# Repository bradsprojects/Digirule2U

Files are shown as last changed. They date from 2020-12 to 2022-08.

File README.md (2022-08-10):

# Digirule 2U by Brad Slattery and Brent Hauser

The Digirule 2U is basically an 8-bit programmable computer from the 1970's built into a 20cm ruler. You can program binary code directly into the Digirule 2U using the push buttons and LED's or you can write programs in assembly language on your computer then download them to the Digirule 2U via USB.

All files to make your own Digirule 2U are included in this repository, however you can also buy a pre-made version from my Tindie store - (https://www.tindie.com/products/bradsprojects/digirule2-the-8-bit-programmable-binary-ruler/)

There are online versions of the user manuals available here:

1. Digirule 2U User Manual (https://hackmd.io/@zrqJxVrZQz-EScD0kFIEYg/rJ6S9s4SP)
2. ADR2 Digirule 2U Cross-Assembler User Manual (https://hackmd.io/@zrqJxVrZQz-EScD0kFIEYg/rJ3bYYtqw)
3. DLDR2 Digirule 2U Download Utility User Manual (https://hackmd.io/@zrqJxVrZQz-EScD0kFIEYg/rkCUtKF9v)
4. UDR2 Digirule 2U Firmware Updater User Manual (https://hackmd.io/@zrqJxVrZQz-EScD0kFIEYg/B1gSKYK5w)
5. Digirule 2U FAQs (https://hackmd.io/@zrqJxVrZQz-EScD0kFIEYg/HkEHDYwAD)

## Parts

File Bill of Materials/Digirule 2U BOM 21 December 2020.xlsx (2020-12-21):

Digirule 2U BOM
Item | Reference | Qty | Description | Manufacturer Part Number | Manufacturer | Digikey Part Number | LCSC Part Number | Link
1 | B1 | 1 | CR2032 Battery Holder SMD | BS-8-1 | Q&J |  | C70378 | LINK (https://lcsc.com/product-detail/Battery-Holders-Clips-Contacts_CR2032battery-Gold-plated-patch-horizontal-base_C70378.html)
2 | C1, C2, C5, C9 | 4 | 0402 100nF Capacitor | CL05B104KO5NNNC | Samsung Electro-Mechanics |  | C1525 | LINK (https://lcsc.com/product-detail/Multilayer-Ceramic-Capacitors-MLCC-SMD-SMT_SAMSUNG_CL05B104KO5NNNC_100nF-104-10-16V_C1525.html)
3 | C3, C4 | 2 | 0402 4.7uF Capacitor | JMK105BBJ475MV-F | Taiyo Yuden |  | C87147 | LINK (https://lcsc.com/product-detail/Multilayer-Ceramic-Capacitors-MLCC-SMD-SMT_TAIYO-YUDEN_JMK105BBJ475MV-F_4-7uF-475-20-6-3V_C87147.html)
4 | C6 | 1 | 0402 10nf Capacitor | TCC0402X7R103K500AT | CCTC |  | C688874 | LINK (https://lcsc.com/product-detail/Multilayer-Ceramic-Capacitors-MLCC-SMD-SMT_CCTC-TCC0402X7R103K500AT_C688874.html)
5 | C7, C8 | 2 | 0402 47pF Capacitor | 0402CG470J500NT | FH(Guangdong Fenghua Advanced Tech) |  | C1567 | LINK (https://lcsc.com/product-detail/Multilayer-Ceramic-Capacitors-MLCC-SMD-SMT_FH-Guangdong-Fenghua-Advanced-Tech-0402CG470J500NT_C1567.html)
6 | D1, D2, D3, D4, D5, D6, D7, D8, D9, D10, D11, D12, D13, D14, D15, D16, D17, D18 | 18 | 0805 Red LED | FC-2012HRK-620D | Foshan NationStar Optoelectronics |  | C84256 | LINK (https://lcsc.com/product-detail/Light-Emitting-Diodes-LED_Red-LED-SMDLED-80-180mcd_C84256.html)
7 | D19, D20 | 2 | 30V, 800mA 220mV @ 10mA SOD-323 Schottky Diode | CUS08F30,H3F | Toshiba |  | C150183 | LINK (https://lcsc.com/product-detail/Schottky-Barrier-Diodes-SBD_TOSHIBA_CUS08F30-H3F_CUS08F30-H3F_C150183.html)
8 | FB1 | 1 | 0402 Ferrite Bead 600ohm @ 100MHz | BLM15AX601SN1D | Murata Electronics |  | C76886 | LINK (https://lcsc.com/product-detail/Ferrite-Beads_Murata-Electronics_BLM15AX601SN1D_Murata-Electronics-BLM15AX601SN1D_C76886.html)
9 | J1 | 1 | USB - Type C Female 16 SMD USB Connectors RoHS | C167321 | Jing Extension of the Electronic Co. |  | C167321 | LINK (https://lcsc.com/product-detail/USB-Connectors_Jing-Extension-of-the-Electronic-Co-C167321_C167321.html)
10 | R1, R2, R3, R4, R5, R6, R7, R8, R9, R10, R11, R12, R13, R14, R15, R16, R17, R18, R28 | 19 | 0402 1k 5% tolerance thick film resistor | RC0402JR-071KL | YAGEO |  | C105637 | LINK (https://lcsc.com/product-detail/Chip-Resistor-Surface-Mount_1KR-102-5_C105637.html)
11 | R19, R20, R21, R22, R23, R24, R25, R29, R30 | 9 | 0402 10k 5% tolerance thick film resistor | RC0402FR-0710KL | YAGEO |  | C60490 | LINK (https://lcsc.com/product-detail/Chip-Resistor-Surface-Mount_10KR-1002-1_C60490.html)
12 | R26, R27 | 2 | 27Ω ±1% 1/16W ±1% ±200ppm/℃ 0402 Chip Resistor - Surface Mount RoHS | 0402WGF270JTCE | Viking Tech |  | C25100 | LINK (https://lcsc.com/product-detail/Chip-Resistor-Surface-Mount_UNI-ROYAL-Uniroyal-Elec-0402WGF270JTCE_C25100.html)
13 | R31, R32 | 2 | 0402 5.1k 5% tolerance thick film resistor | AR02DTD5101 | UNI-ROYAL(Uniroyal Elec) |  | C319557 | LINK (https://lcsc.com/product-detail/Others_Viking-Tech-AR02DTD5101_C319557.html)
14 | SW1, SW2, SW3, SW4, SW5, SW6, SW7, SW8, SW9, SW10, SW11, SW12, SW13, SW14, SW15 | 15 | SMD Button 6*6*2.5mm | K2-1157SP-C4SB-01 | Korean Hroparts Elec |  | C128947 | LINK (https://lcsc.com/product-detail/Tactile-Switches_Switch-6-4mm-6-0mm-3-1_C128947.html)
15 | SW16 | 1 | Power Slide Switch SMD | K3-1296S-E2 | Korean Hroparts Elec |  | C136659 | LINK (https://lcsc.com/product-detail/Toggle-Switches_K3-1296S-E2_C136659.html)
16 | U1 | 1 | PIC18F46K20-I/PT | PIC18F46K20-I/PT | Microchip Tech |  | C70902 | LINK (https://lcsc.com/product-detail/MICROCHIP_MICROCHIP_PIC18F46K20-I-PT_PIC18F46K20-I-PT_C70902.html)
17 | U2 | 1 | USB to UART 12-DFN(3x3) | FT-234XD-R | FTDI | 768-1178-1-ND |  | LINK (https://www.digikey.com/product-detail/en/ftdi-future-technology-devices-international-ltd/FT234XD-R/768-1178-1-ND/3904926)
18 | U3 | 1 | LVC Single AND Gate | SN74LVC1G08DCKR | Texas Instruments |  | C7832 | LINK (https://lcsc.com/product-detail/Gates-and-Inverters_Texas-Instruments_SN74LVC1G08DCKR_Texas-Instruments-Texas-Instruments-SN74LVC1G08DCKR_C7832.html)

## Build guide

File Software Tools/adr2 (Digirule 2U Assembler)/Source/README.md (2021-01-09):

Compile adr2 (Digirule 2U Cross-Assembler)
-------------------------------------------

You can compile the Digirule 2U Cross-Assembler from the terminal under Linux or Mac OS, or from the command prompt under Windows.

Note: You will need to make sure that git and gcc are installed on your system before running the following commands.

For Linux, use the following:
```
git clone https://github.com/bradsprojects/Digirule2U
cd Digirule2U/Software\ Tools/adr2\ \(Digirule\ 2U\ Assembler\)/Source
gcc -Wall -Os -s *.c -o adr2
```

For Mac OS, use the following:
```
git clone https://github.com/bradsprojects/Digirule2U
cd Digirule2U/Software\ Tools/adr2\ \(Digirule\ 2U\ Assembler\)/Source
gcc -Wall -Os *.c -o adr2
```

For Windows, use following:
```
git clone https://github.com/bradsprojects/Digirule2U
cd Digirule2U\Software Tools\adr2 (Digirule 2U Assembler)\Source
gcc -Wall -Os -s *.c -o adr2.exe
```

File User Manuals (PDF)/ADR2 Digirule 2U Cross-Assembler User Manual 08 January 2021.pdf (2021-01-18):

# ADR2 Digirule 2U Cross-Assembler User Manual

8 January 2021

# Introduction

ADR2 is a traditional style command line cross-assembler for the Digirule 2U. Its purpose is to translate assembly language program source into machine code for downloading to the Digirule 2U. Versions are available for Linux, Mac OS and Windows.

The assembler has the following features:

Supports the entire Digirule 2U instruction set
Supports directives for control of the assembly and listing process
Supports definition of symbolic names to represent memory addresses and constants Supports symbolic expressions with a comprehensive set of operators
Supports pre-defined symbols for commonly-used Digirule 2U resources
Supports numbers represented in binary, decimal, hexadecimal and character notation Produces a formatted listing file which includes location counter, machine code, source line, symbol table and RAM usage information
Two-pass assembly
Directly produces machine code in Intel Hex format for download to the Digirule 2U

# Invoking the Assembler

The assembler is invoked using the following general syntax:

The assembler reads the source input from standard input by default, so it may be redirected from a file, device or another program as desired. The assembler writes the hex output to standard output by default, so it may be redirected to a file, device or another program as desired.

The assembler supports the following command-line options:

adr2 [options] <sourcefile >hexfile

Option | Function
--quiet | suppress banner and completion info
--nolist | suppress listing file creation
--list [path] | specify alternate listing file pathname (default is adr2.lst )
--help | display help information

Here are a few examples of how to invoke the assembler:

listing to adr2.lst , hex to sample.hex

no listing, hex to sample.hex

listing to sample.lst , hex to sample.hex

listing to sample.lst , hex downloaded to Digirule 2U^*^ (Linux)

listing to sample.lst , hex downloaded to Digirule 2U^*^ (via dldr2 download utility, Mac)

listing to sample.lst , hex downloaded to Digirule 2U^*^ (Windows)

Tip: For Windows, if the port device name is COM10 or greater, it must be specified as

\\.\COMnn
^*^This example requires the Digirule 2U to be in Comm Load Mode prior to execution. Please refer to the Digirule 2U User Manual for details on setting the mode.

The assembler returns a value to the operating system indicating if errors or warnings were encountered during assembly.

adr2 < sample.asm > sample.hex

adr2 --nolist < sample.asm > sample.hex

adr2 --list sample.lst < sample.asm > sample.hex

stty -F /dev/ttyUSB0 9600 cs8 -parenb -cstopb adr2 --list sample.lst < sample.asm > /dev/ttyUSB0

adr2 --list sample.lst < sample.asm | dldr2 /dev/tty.usbserial-FTxxxxxx

mode COM3 baud=9600 data=8 parity=n stop=1 adr2 --list sample.lst < sample.asm > COM3

Return Value | Meaning
0 | Success
1 | Warning(s)
2 | Error(s)
3 | Fatal error
Category | Characters
Whitespace | space, horizontal tab
Letters | A..Z, a..z
Digits | 0..9
Punctuation | ! " # $ % & ' ( ) * + , - . / : ; < = > ? @ [ \ ] ^ _ ` { | } ~
Line Feed | 0x0A

# Assembler Input

The assembler recognizes the following characters for source input. All other characters are ignored.

# Source File Format

A program is written as one or more source files. A source file consists of source lines, each with a specific format. The main source file typically starts with an ORG directive to set the initial location counter, and an END directive to mark the end of assembly (and optionally specify the program entry point).

Tip: If the ORG directive is omitted, the location counter defaults to 0 at the beginning of assembly.

Tip: If the END directive is omitted, assembly stops at the end of the file, and the program entry point defaults to 0.

## Source Line Format

Each source line has a specific format consisting of up to four fields. Fields are separated by whitespace (one or more horizontal tab or space characters), so fields may not contain whitespace. The exceptions are inside quoted character constant operands and comments. The fields, in order from left to right, are:

Label Field

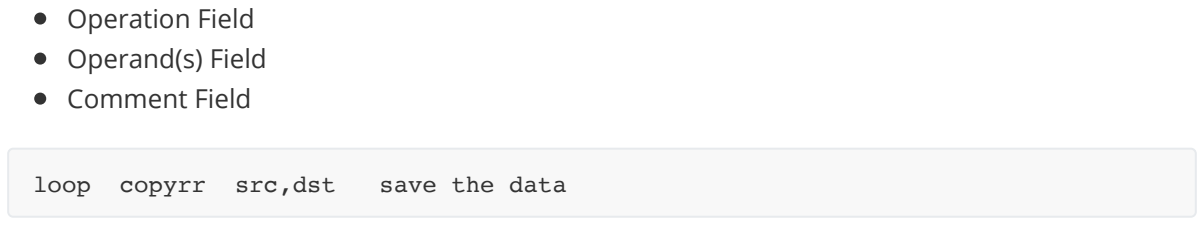
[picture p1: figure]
Operation Field Operand(s) Field Comment Field; loop; copyrr; src,dst; save the data

The maximum length of a line is 255 characters. Any characters beyond this limit are ignored.

## Label Field

The label field optionally contains a user-defined label. If a label is present, its first character must be an underscore or a letter. Subsequent characters may be underscores, letters or digits. The maximum length of a label is 255 characters. Labels are case-sensitive, i.e. LOOP and loop are distinct. A label will assume the current value of the location counter unless the operation field is the EQU directive, in which case the label will assume the value of the expression following the directive.

## Operation Field

The operation field optionally contains an instruction mnemonic or an assembler directive. If no instruction is present, no machine code will be emitted for that line. Instruction mnemonics and directives are not case sensitive.

## Operand Field

The operand field contains any operand(s) required by the operation field instruction or directive. If multiple operands are required, they must be separated by commas. It is an error to have too few or too many operands for a given operation.

## Comment Field

The comment field optionally contains human readable text typically used to document the program. The assembler ignores the contents of this field, except that it is written to the listing file.

Tip: If a comment is desired on a line lacking an operation or operand, the comment must begin with a semicolon ; .

Tip: A line that begins with an asterisk * or a semicolon ; is treated as a comment and ignored.

# Directives

The assembler supports the following directives:

Directive | Function
BYTE exp [,...] | Defines one or more bytes starting at the current location counter and initializes them to exp [,...]
END [exp] | Optionally marks the end of the assembly source file. Any lines that follow will be ignored. The optional exp specifies the program entry point, which will be automatically loaded into the Digirule 2U Program Counter upon download.
label EQU exp | Assigns the new symbol label the value exp. This is the only way to assign a value other than the location counter to a label. exp must not reference a forward or undefined symbol.
INCLUDE file | Include the contents of another source file. Included files may themselves include other files, up to a system-dependent depth. The remainder of the including source file will be processed after the entire included source file is processed.
LIST | Include the following lines in the listing file.
NOLIST | Exclude the following lines from the listing file.
NOPAGE | Suppress page generation in the listing file. Once specified, it is not possible to return to automatic page generation.
ORG exp | Changes the location counter to exp. Subsequent lines are assigned memory locations starting at the new location counter value. exp must not be a value lower than the current location counter.
PAGE | Starts a new page in the listing file.
SPACE exp | Advances the location counter to reserve exp bytes of memory. The memory is not initialized in any way. This directive, preceded by a label, is typically used to create an uninitialized buffer.

# Constants

Numeric constants may be expressed in binary, decimal, hexadecimal or character notation.

Radix | Example
Binary | 0b01000001
Decimal | 65
Hexadecimal | 0x41
Character | ‘A’
Location counter | *
Operator | Function
( , ) | Change the order of evaluation
+ , - , ~ | Unary plus, unary minus, unary not
<< , >> , <<< , >>> | Shift left, shift right, rotate left, rotate right
& | And
^ | Exclusive-or
| | Or
** | Power
* , / , % | Multiply, divide, modulo (remainder)
+ , - | Add, subtract

Tip: To embed a quote character within a quoted character or string constant, use two
adjacent quotes, e.g. str | byte | ‘Brent’’s Digirule 2U’,0

# Expression Operators

The following assembly-time operators are supported, grouped by equal precedence, in decreasing order of precedence:

Symbols are stored, and symbolic expressions are evaluated, with 16-bit precision.

# Predefined Symbols

The following symbols are conveniently predefined by the assembler:

Symbol | Resource | Value
_z | Status register Zero bit | 0x00
_c | Status register Carry bit | 0x01
_sar | Status register Show Address Register bit | 0x02
_sr | Status register | 0xFC
_br | Button register | 0xFD
_ar | Address LEDs register | 0xFE
_dr | Data LEDs register | 0xFF

### EXAMPLE

# Assembler Output

## Hex File

The hex file contains the assembler-generated machine code in Intel Hex format, suitable for download to the Digirule 2U. Each line is a record, consisting of the following fields:

start character ( : )
data field byte count (two digits)
starting memory address (four digits)
record type ( 00 for data record, 01 for end-of-file record)
data field (up to 32 digits)
checksum (two digits)

Record type 00 is a data record containing data to initialize Digirule 2U memory. Record type 01 is an end-of-file record containing the program entry point address. Only those memory locations containing instructions or data generated with the BYTE directive are included in the hex file and written to Digirule 2U memory during download. Other memory locations will remain unchanged. This permits downloading multiple programs to different addresses if desired.

## Listing File

The listing file combines the source code and the corresponding assembler-generated machine code for easy cross reference. It is an invaluable source of information when debugging a program. From left to right, a typical listing line contains:

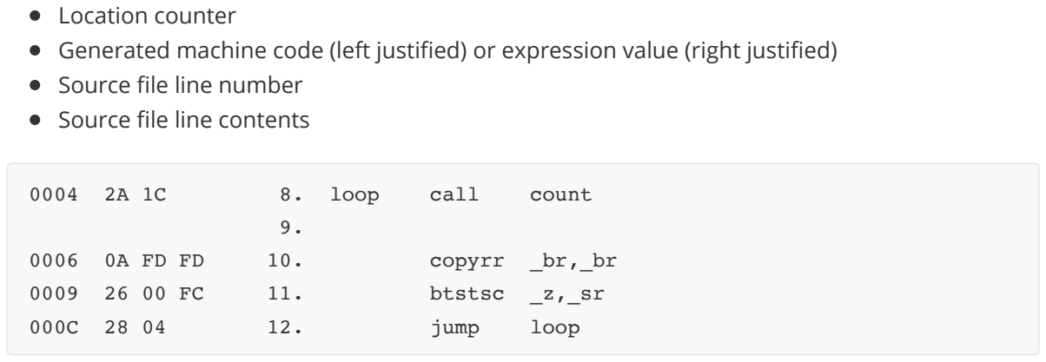
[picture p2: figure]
Location counter; Source file line number Source file line contents; loop; call; count; copyrr _br,_br; btstsc _z,_sr; jump

Generated machine code (left justified) or expression value (right justified)

Near the end of the listing file is a dump of the internal symbol table, showing every defined symbol, its associated value, and the source line number at which it was defined.

:10000000032402FC291C0AFDFD2500FC27041EF028 :10001000291C0AFDFD2600FC271027042301FC25CE :1000200000F0273709F1110F07F109FF110007FF51 :1000300009FE110007FE2B09F1130F07F109FF1349 :0A0040000007FF09FE130007FE2B66 :0100F000000F
:00000001FF
Line | Val | Symbol
0 | 00FE _ar
0 | 00FD _br
0 | 0001 _c
0 | 00FF _dr
0 | 0002 _sar
0 | 00FC _sr
0 | 0000 _z
61 | 00F1 | byte0
67 | 00FF | byte1
64 | 00FE | byte2
24 | 001C | count
59 | 00F0 | dir
43 | 0037 | down
8 | 0004 | loop
16 | 0010 | loop2
5 | 0000 | start
1 | 000F | step

At the far end is a RAM usage table, showing which memory locations will be written when the corresponding hex file is downloaded to the Digirule 2U.

# Sample Source File

RAM Usage
0000 | XXXXXXXXXXXXXXXX
0010 | XXXXXXXXXXXXXXXX
0020 | XXXXXXXXXXXXXXXX
0030 | XXXXXXXXXXXXXXXX
0040 | XXXXXXXXXX......
0050 | |
0060 | |
0070 | |
0080 | |
0090 | |
00A0 | |
00B0 | |
00C0 | |
00D0 | |
00E0 | |
00F0 | X |
step | equ | 15
| org | 0
start | initsp
| bset | _sar,_sr
loop | call | count

copyrr _br,_br
btstsc _z,_sr
| jump | loop
| incr | dir
loop2 | call | count

copyrr _br,_br
btstss _z,_sr
| jump | loop2

| jump | loop
count | bclr | _c,_sr
| btstsc | 0,dir
| jump | down
up | copyra | byte0
| addla | step
| copyar | byte0
| copyra | byte1
| addla | 0
| copyar | byte1
| copyra | byte2
| addla | 0
| copyar | byte2
| return
down | copyra | byte0
| subla | step
| copyar | byte0
| copyra | byte1
| subla | 0
| copyar | byte1
| copyra | byte2
| subla | 0
| copyar | byte2
| return
| org | 0xF0
dir | byte | 0
byte0 | space | 1
| org | _ar
byte2 | space | 1
| org | _dr
byte1 | space | 1
| end | start

# Sample Listing File

Digirule 2U Cross-Assembler | Wed Sep 23 10:55:53 2020 | Page 1
| 000F | 1. | step | equ | 15
| | 2.
0000 | | 3. | | org | 0
| | 4.
0000 | 03 | 5. | start | initsp
0001 | 24 02 FC | 6. | | bset | _sar,_sr
| | 7.
0004 | 2A 1C | 8. | loop | call | count
| | 9.
0006 | 0A FD FD | 10. | copyrr _br,_br
0009 | 26 00 FC | 11. | btstsc _z,_sr
000C | 28 04 | 12. | | jump | loop
| | 13.
000E | 1E F0 | 14. | | incr | dir
| | 15.
0010 | 2A 1C | 16. | loop2 | call | count
| | 17.
0012 | 0A FD FD | 18. | copyrr _br,_br
0015 | 27 00 FC | 19. | btstss _z,_sr
0018 | 28 10 | 20. | | jump | loop2
| | 21.
001A 28 04 | 22. | jump | loop
| | 23.
001C | 23 01 FC | 24. | count | bclr | _c,_sr
| | 25.
001F | 26 00 F0 | 26. | | btstsc | 0,dir
0022 | 28 37 | 27. | | jump | down
| | 28.
0024 | 09 F1 | 29. | up | copyra | byte0
0026 | 11 0F | 30. | | addla | step
0028 | 07 F1 | 31. | | copyar | byte0
| | 32.
002A 09 FF | 33. | copyra | byte1
002C | 11 00 | 34. | | addla | 0
002E | 07 FF | 35. | | copyar | byte1
| | 36.
0030 | 09 FE | 37. | | copyra | byte2
0032 | 11 00 | 38. | | addla | 0
0034 | 07 FE | 39. | | copyar | byte2
| | 40.
0036 | 2C | 41. | | return
| | 42.
0037 | 09 F1 | 43. | down | copyra | byte0

0039 | 13 0F | 44. | | subla | step
003B | 07 F1 | 45. | | copyar | byte0
| | 46.
003D | 09 FF | 47. | | copyra | byte1
003F | 13 00 | 48. | | subla | 0
0041 | 07 FF | 49. | | copyar | byte1
| | 50.
0043 | 09 FE | 51. | | copyra | byte2
0045 | 13 00 | 52. | | subla | 0
0047 | 07 FE | 53. | | copyar | byte2
| | 54.
0049 | 2C | 55. | | return
| | 56.
00F0 | | 57. | | org | 0xF0
| | 58.
Digirule 2U Cross-Assembler | Wed Sep 23 10:55:53 2020 | Page 2
00F0 | 00 | 59. | dir | byte | 0
| | 60.
00F1 | | 61. | byte0 | space | 1
| | 62.
00FE | | 63. | | org | _ar
00FE | | 64. | byte2 | space | 1
| | 65.
00FF | | 66. | | org | _dr
00FF | | 67. | byte1 | space | 1
| | 68.
0100 | 0000 | 69. | end | start

Assembly complete
0 errors
0 warnings
Line | Val | Symbol
0 | 00FE _ar
0 | 00FD _br
0 | 0001 _c
0 | 00FF _dr
0 | 0002 _sar
0 | 00FC _sr
0 | 0000 _z
61 | 00F1 | byte0
67 | 00FF | byte1
64 | 00FE | byte2
24 | 001C | count
59 | 00F0 | dir
43 | 0037 | down

8 | 0004 | loop
16 | 0010 | loop2
5 | 0000 | start
1 | 000F | step
29 | 0024 | up

RAM Usage
0000 | XXXXXXXXXXXXXXXX
0010 | XXXXXXXXXXXXXXXX
0020 | XXXXXXXXXXXXXXXX
0030 | XXXXXXXXXXXXXXXX
0040 | XXXXXXXXXX......
0050 | |
0060 | |
0070 | |
0080 | |
0090 | |
00A0 | |
00B0 | |
00C0 | |
00D0 | |
00E0 | |
00F0 | X |

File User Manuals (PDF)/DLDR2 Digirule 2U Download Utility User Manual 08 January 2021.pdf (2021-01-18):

# DLDR2 Digirule 2U Download Utility User Manual

8 January 2021

# Introduction

DLDR2 is a utility designed to make it easier to download programs from a Mac to the Digirule 2U. Specifically, its purpose is to work around a difficulty with configuring the serial port from the Mac command line. This manual should be considered a supplement to the Digirule 2U User Manual.

# Getting Started

Before running the utility, you need to know the name of the USB device on your Mac to which the Digirule 2U is connected.

ls /dev/tty.*

Example device name: /dev/tty.usbserial-DM038QQY

# Running the Utility

The general syntax to invoke the utility is:

dldr2 <file device
This example assumes that the utility resides in the current working directory.

User@imac:~ $ ./dldr2 < program.hex /dev/tty.usbserial-DM038QQY

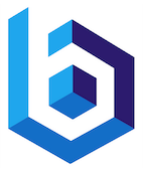
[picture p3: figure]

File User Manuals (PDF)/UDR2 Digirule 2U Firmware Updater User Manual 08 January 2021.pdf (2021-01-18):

# UDR2 Digirule 2U Firmware Updater User Manual

8 January 2021

# Introduction

UDR2 is a utility used to install firmware updates on the Digirule 2U. Versions are available for Linux, Mac OS and Windows. This manual should be considered a supplement to the Digirule 2U User Manual.

# Getting Started

Before running the utility, you need to download from the Digirule 2U website the hex file for the firmware you want to install.

Example firmware file: dr2u.firmware.22sep2020.hex

You also need to know the name of the USB device on your computer to which the Digirule 2U is connected.

## Linux

ls /dev/tty*
Example device name: /dev/ttyUSB0

## Mac

ls /dev/tty.*

Example device name: /dev/tty.usbserial-DM038QQY

## Windows

mode , or use Device Manager

Example device name: COM3

And finally, the Digirule 2U must be in the proper mode to receive the firmware. Please refer to the Digirule 2U User Manual section Updating the Firmware for details on the exact procedure.

# Running the Utility

The general syntax to invoke the utility is:

udr2 [options] <file device
The utility supports the following command-line options:

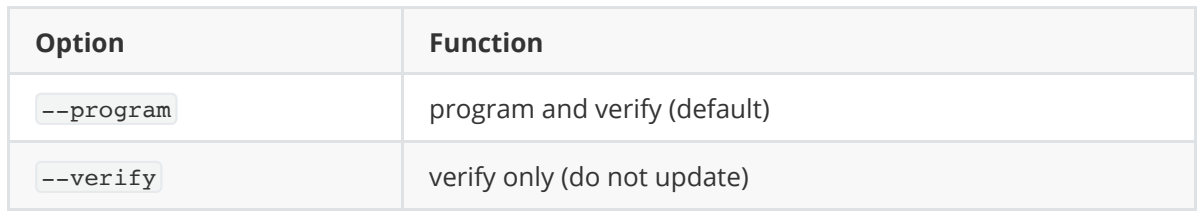
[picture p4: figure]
Option; Function; --program; program and verify (default); --verify; verify only (do not update)

Invoking the utility is slightly different depending on which operating system you use. All of these examples assume that the utility resides in the current working directory.

## Linux

## Mac

## Windows

pi@rpi0:~ $ ./udr2 < dr2u.firmware.22sep2020.hex /dev/ttyUSB0
Digirule 2U Firmware Updater | 18 Dec 2020 | KD0GLS
Loading hex file... OK
Opening port... OK
Erasing flash... OK
Writing flash | OK
Verifying flash | OK
Restarting Digirule... OK
Closing port... OK

User@imac:~ $ ./udr2 < dr2u.firmware.22sep2020.hex /dev/tty.usbserial-DM038QQY
Digirule 2U Firmware Updater | 18 Dec 2020 | KD0GLS
Loading hex file... OK
Opening port... OK
Erasing flash... OK
Writing flash | OK
Verifying flash | OK
Restarting Digirule... OK
Closing port... OK

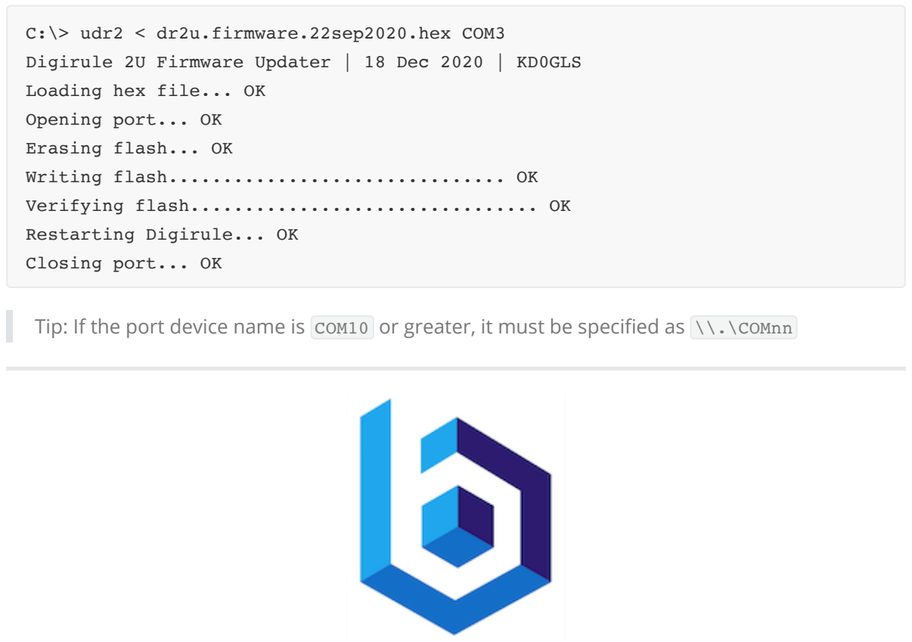
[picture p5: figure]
C:\> udr2 < dr2u.firmware.22sep2020.hex COM3; Loading hex file... OK; Opening port... OK; Erasing flash... OK; Writing flash............................... OK; Verifying flash................................ OK; Restarting Digirule... OK; Closing port... OK

Tip: If the port device name is COM10 or greater, it must be specified as \\.\COMnn

Digirule 2U Firmware Updater | 18 Dec 2020 | KD0GLS

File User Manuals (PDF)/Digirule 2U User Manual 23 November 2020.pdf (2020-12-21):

# Digirule 2U User Manual

23 November 2020

# Description

The Digirule 2U is an Open Source Hardware programmable 8-bit binary computer built into a 20 cm (8”) PCB ruler.

Full details can be found here: bradsprojects.com/digirule2

# Features and Specifications

Microchip PIC18F46K20 8-bit microcontroller
USB-C interface with FTDI FT234XD virtual-COM port controller 8-bit address bus
8-bit data bus
256 bytes program/data RAM (4 bytes reserved for registers) Eight non-volatile memory files to back up your programs 54 instructions
Adjustable instruction execution interval (speed)
64-level stack
Eight Address LEDs, eight Data LEDs, Run and Stop LEDs Eight Data input buttons
File Load and Save buttons
Address Goto, Previous and Next buttons
Data Store button
CPU Run/Stop button
Built-in Debug Monitor
Built-in Firmware Updater
Expansion Port with UART, Pin I/O and ICSP interfaces
Powered by 3-volt CR2032 coin cell battery
Instruction set reference chart
Dimensions: 210 mm (8.27") L x 40 mm (1.57") W x 7 mm (0.28") H Weight: 37 grams (1.3 oz) including battery

# Overview

## Front Side

The front of the Digirule 2U contains the battery, power switch, microcontroller, buttons, LEDs, USB-C port and Expansion Port.

## Rear Side

The rear of the Digirule 2U contains a chart of the instruction set and reserved registers, and a Help section. It also features an Open Source Hardware logo and a QR-Code which will take you to the Digirule 2 webpage. The Expansion Port is also accessible. And finally, a dedication to our good friend Olivier Lecluse, who was a great help to us in the development of the Digirule 2U.

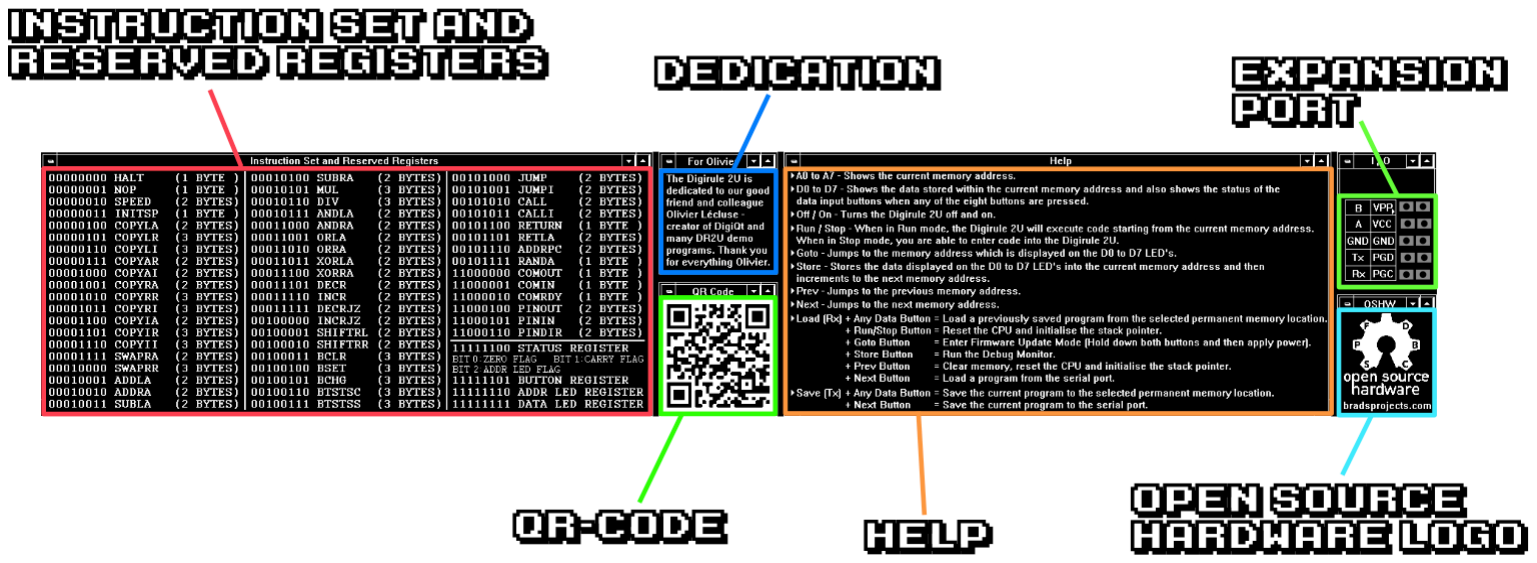
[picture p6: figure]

# History

The Digirule 2U is the third edition of the Digirule 2 series of portable computers. The first was the Digirule 2, while the second was the Digirule 2A. The Digirule 2U represents a significant hardware and software upgrade compared to the previous versions.

The Digirule 2U differs from its predecessor (the Digirule 2A) in the following ways:

PIC18F46K20 microcontroller (Digirule 2A uses PIC18F45K20 microcontroller) Microcontroller clock speed is 16 MHz (Digirule 2A microcontroller clock speed is 8 MHz) USB-C and UART communications interfaces
Expansion Port
54 instructions, including multiply and divide (Digirule 2A has 35 instructions)
COPYxx instructions now update the Zero status flag
ADDxx and SUBxx instructions now include the Carry status flag in their calculation

RANDA instruction has been significantly improved CPU performance has been significantly improved CPU stack depth is 64 (Digirule 2A stack depth is 4)
Built-in Debug Monitor
Built-in Firmware Updater
Supported by full-featured adr2 assembler and udr2 firmware updater

# Conventions Used in This Manual

Most numbers are presented in both hexadecimal and binary, using the following notation:

0xA5 (10100101)

Some small numbers (for example bit numbers) are presented in decimal and binary:

7 (00000111)

# Operation

## Getting Started

It is important that care be taken when installing the CR2032 battery. First make sure the battery's positive side is facing up (away from the Digirule 2U) and the battery is slotted under the metal tab at the front of the holder. Then press down on the opposite end of the battery until it snaps under the plastic retaining tabs. Failure to follow this procedure may result in damage to the battery holder.

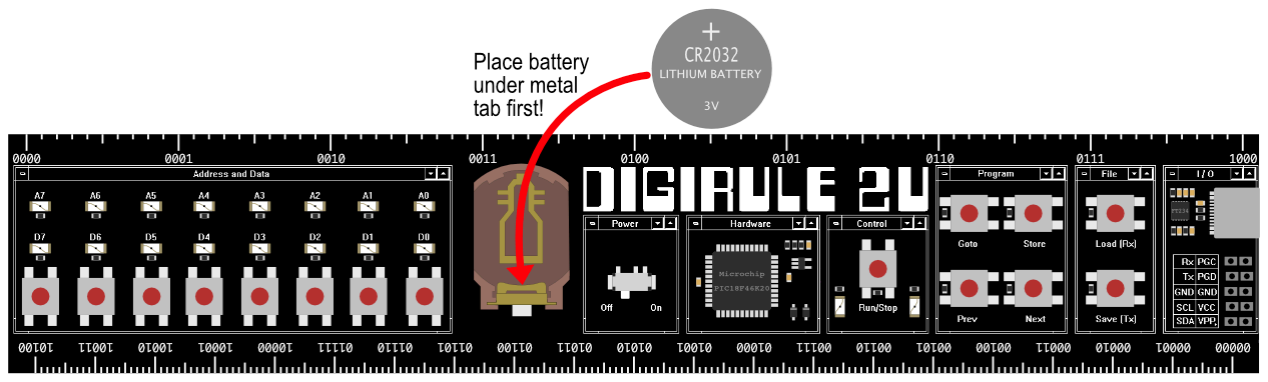
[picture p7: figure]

The power switch turns the Digirule 2U on or off when using the battery as the power source. The Digirule 2U is always on when connected to a USB power source, regardless of the power switch setting.

When powered on, the Digirule 2U performs a brief LED animation so you can verify all of the LEDs are functioning. RAM is cleared and the CPU is reset. The Digirule 2U is now ready for use.

Action | Steps
Clear RAM | Press and hold the Load button, then press the Prev button.
Edit RAM | Use the Data, Goto, Prev, Next and Store buttons.
Load RAM from a non-volatile memory file | Press and hold the Load button, then press a Data button.
Save RAM to a non-volatile memory file | Press and hold the Save button, then press a Data button.
Load RAM from the Comm Port | Press and hold the Load button, then press the Next button. The Digirule 2U enters Comm Load mode.
Save RAM to the Comm Port | Press and hold the Save button, then press the Next button. The Digirule 2U enters Comm Save mode.
Reset the CPU | Press and hold the Load button, then press the Run/Stop button.
Start the CPU | Press the Run/Stop button. The Digirule 2U enters Run mode.
Start the Debug Monitor | Press and hold the Load button, then press the Store button. The Digirule 2U enters Monitor mode.
Action | Steps
Provide input to the program | Press any Data button(s).
Turn on or off the Address LEDs | Press the Goto button.
Stop the CPU | Press the Run/Stop button. The Digirule 2U enters Stop mode.

## Modes of Operation

The Digirule 2U is in one of the following five modes of operation at any point in time:

### Stop Mode

This is the mode from which most of the Digirule 2U functions are accessed. In this mode, the Stop LED is on and the CPU is stopped, and you can:

The Address LEDs display the contents of the Program Counter. The Data LEDs display the contents of RAM addressed by the Program Counter.

### Run Mode

In this mode, the Run LED is on and the CPU is executing instructions, and you can:

LED | Meaning
D7 | Listening status (blinking)

D6-D3

D2 | Record type error
D1 | Checksum error
D0 | Non-hex character error
LED | Meaning

D7

D6 | Talking status (blinking)

D5-D0

Unless turned off, the Address LEDs display the contents of the Program Counter (if bit 2 of the Status Register is clear) or the contents of the Address LEDs Register (if bit 2 of the Status Register is set). The Data LEDs display the contents of the Data LEDs Register.

### Comm Load Mode

In this mode, RAM is loaded with data (in Intel Hex format) from the Comm Port. The Address LEDs display a progress bar. The Data LEDs display status as follows:

When the data has been fully received, the Listening status LED stops blinking. If an error occurred, the error LED starts blinking, and you need to press any Data button to clear the error condition. The Digirule 2U then automatically resets the CPU, sets the Program Counter to the entry point of the program, and enters Stop mode.

This mode can be cancelled by pressing the Run/Stop button, and the Digirule 2U enters Stop mode.

Note: The Comm Port configuration is 9600 baud, 8 data bits, no parity, 1 stop bit.

### Comm Save Mode

In this mode, RAM is saved (in Intel Hex format) to the Comm Port. The Address LEDs display a progress bar. The Data LEDs display status as follows:

When the data has been fully transmitted, the Talking status LED stops blinking, and the Digirule 2U enters Stop mode.

This mode can be cancelled by pressing the Run/Stop button, and the Digirule 2U enters Stop mode.

Note: The Comm Port configuration is 9600 baud, 8 data bits, no parity, 1 stop bit.

### Monitor Mode

In this mode, the built-in Debug Monitor is active on the Comm Port. See the Using the Debug Monitor section for information on how to use the monitor.

This mode can be cancelled by pressing the Run/Stop button, and the Digirule 2U enters Stop mode.

## Entering a Program

With the Digirule 2U in Stop mode, you can enter a program into RAM using the eight Data buttons and the four Program window buttons. The Program Counter contains the address of (points to) the RAM location currently being edited, and is displayed on the Address LEDs. The contents of the addressed RAM location is displayed on the Data LEDs. Refer to the handy chart on the rear of the Digirule 2U to find opcode values for specific instructions.

Tip: To quickly fill all of RAM with zeros, press and hold the Load button, then press the Prev button.

To modify the value displayed on the Data LEDs, press the button below the particular LED whose state you want to change. If the LED is off, pressing the corresponding button turns it on, and vice-versa.

Tip: To quickly fill all of the Data LEDs with zeros, press and hold the Data 0 button for one second. To fill all of the Data LEDs with ones, press and hold the Data 7 button for one second.

To set the Program Counter (RAM address), first enter the address on the Data LEDs, then press the Goto button to transfer it to the Program Counter (and the Address LEDs). The contents of the RAM location addressed by the Program Counter is displayed on the Data LEDs. Alternatively, you can use the Prev and Next buttons to decrement or increment the Program Counter by one with each press of the button.

Once the Program Counter is set to the desired address, you can then modify the contents of that RAM location by first editing the value displayed on the Data LEDs, then pressing the Store button to write that value to RAM. The Program Counter is automatically incremented to the next address. Use the Prev and Next buttons as desired to review any changes. Repeat this process to enter the rest of your program, then you can run it.

## Running and Stopping a Program

With the Digirule 2U in Stop mode, first make sure the Program Counter (displayed on the Address LEDs) contains the start address (typically 0x00) of the program you want to run, then press the Run/Stop button to start the program. The Stop LED turns off and the Run LED turns on, indicating the Digirule 2U is now in Run mode.

Tip: You can start a program at any address you want. In fact, you can have multiple programs loaded in RAM at the same time, at different addresses. For example, you could have one program at addresses 0x00 to 0x3F and another at addresses 0x40 to 0x7F. To run the first program, set the Program Counter to 0x00 (00000000), then press the Run/Stop button. To run the second program, set the Program Counter to 0x40 (01000000), then press the Run/Stop button.

While in Run mode, the Address LEDs display (by default) the constantly changing address in the Program Counter as the CPU executes instructions. In some cases, this can be a distraction. You can hide this display if desired by pressing the Goto button. To show the display again, press the Goto button again.

To stop a running program, press the Run/Stop button. The Run LED turns off and the Stop LED turns on, indicating the Digirule 2U is now in Stop mode. The internal state of the CPU and all memory and registers is retained. The Program Counter is left pointing to the next instruction to be executed. To resume execution of the program from that point, press the Run/Stop button again. If instead you want to restart the program from the beginning, reset the CPU by first pressing and holding the Load button, then press the Run/Stop button. Then release both buttons, and press the Run/Stop button again to start the program (at address 0x00).

Tip: In some cases you can safely restart a program by simply setting the Program Counter back to the start address and pressing the Run/Stop button. However this method does not reset certain CPU resources back to their default states, so your program may not function as intended. If your program uses the SPEED instruction, the CALL and RETURN instructions (i.e. the stack), or the PIN instructions, you may want to reset the CPU instead.

The CPU will automatically halt and the Digirule 2U enters Stop mode in the following circumstances:

A stack overflow occurs ( CALL instruction is executed with full stack)
A stack underflow occurs ( RETURN instruction is executed with empty stack)
A DIV instruction is executed with zero divisor
A HALT instruction is executed
An invalid instruction opcode is fetched

## Saving and Loading a Program

With the Digirule 2U in Stop mode, you can save the current contents of RAM to any of eight non-volatile memory files. This will retain your program(s) even if the battery is removed. To do this, first press and hold the Save button. The Data LEDs will animate back and forth. Then press one of the eight Data buttons to save the current contents of RAM to that particular file. Then release both buttons.

To load RAM from a previously saved file, first press and hold the Load button. The Data LEDs will animate back and forth. Then press one of the eight Data buttons to load RAM from that particular file. Then release both buttons. The CPU is automatically reset, and the Program Counter is set to 0x00. If that is the correct start address for your program, simply press the Run/Stop button to start it.

Tip: To copy the contents of one file to another, first load RAM from the desired source file, then save it to the desired destination file.

The Digirule 2U comes with eight sample programs preinstalled in each of the eight files.

File | Program | Description
0 | Hello World | Displays "Hello World!" on the terminal using ASCII art.
1 | Prime Numbers | Calculates prime numbers to 255 and displays them on the terminal.
2 | Base Trainer | A game that teaches binary-to-hexadecimal conversion.
3 | Logic Trainer | A game that teaches logic gate functions.
4 | Mastermind | A game where you guess a random 4-digit number.
5 | 24-bit Up/Down Counter | Demonstrates multi-byte addition and subtraction. The upper two bytes of the counter are visible on the Address and Data LEDs (the lower byte is not visible). Press any Data button to reverse the direction of the counter.
6 | Echo | Comm loopback. Any data received from the terminal is transmitted back to the terminal, and displayed on the Data LEDs.
7 | Kill the Bit | A game that starts with a single Data LED shifting right to left. The player needs to press any of the eight Data buttons in an attempt to turn off the lit LED. Pressing a button when the LED above it is on turns it off. However pressing a button when the LED is off turns it on. The goal is to turn off all of the LEDs.

Tip: When you save your own program to a particular file, the sample program previously stored there is deleted. However it can be restored later if desired by downloading the appropriate sample program hex file from the Digirule 2U website, downloading it to RAM via the Comm Port, and saving it to that file again.

# Memory-Mapped Registers

The Digirule 2U has four memory locations reserved for special purpose registers. These are located at the very top of the RAM address space.

Register | Address | Access | Contents
Status Register | 0xFC (11111100) | Read/Write | CPU status flags. See following table.
Button Register | 0xFD (11111101) | Read Only | Data buttons status. For each bit, if that bit is set, the corresponding button is pressed.
Address LEDs Register | 0xFE (11111110) | Read/Write | Displayed on the Address LEDs while in Run mode and only if bit 2 of the Status Register is set.
Data LEDs Register | 0xFF (11111111) | Read/Write | Displayed on the Data LEDs while in Run mode.
Bit | Flag | Description
0 | Z (Zero) | If set, the previous instruction produced a zero result.
1 | C (Carry) | If set, the previous instruction produced a carry or borrow.
2 | Show Address LEDs Register | If set, the Address LEDs display the contents of the Address LEDs Register while in Run mode. If clear, the Address LEDs display the contents of the Program Counter.
3-7 | | Undefined
Opcode | Instruction | Description | Bytes | Flags
0x00 | HALT | Stop the CPU | 1
0x01 | NOP | No operation | 1
0x02 | SPEED | Set instruction execution interval | 2
0x03 | INITSP | Initialise Stack Pointer | 1
0x04 | COPYLA | Copy literal to Accumulator | 2 | Z
0x05 | COPYLR | Copy literal to RAM | 3 | Z
0x06 | COPYLI | Copy literal to RAM indirect | 3 | Z

## Status Register

# Instruction Set Summary

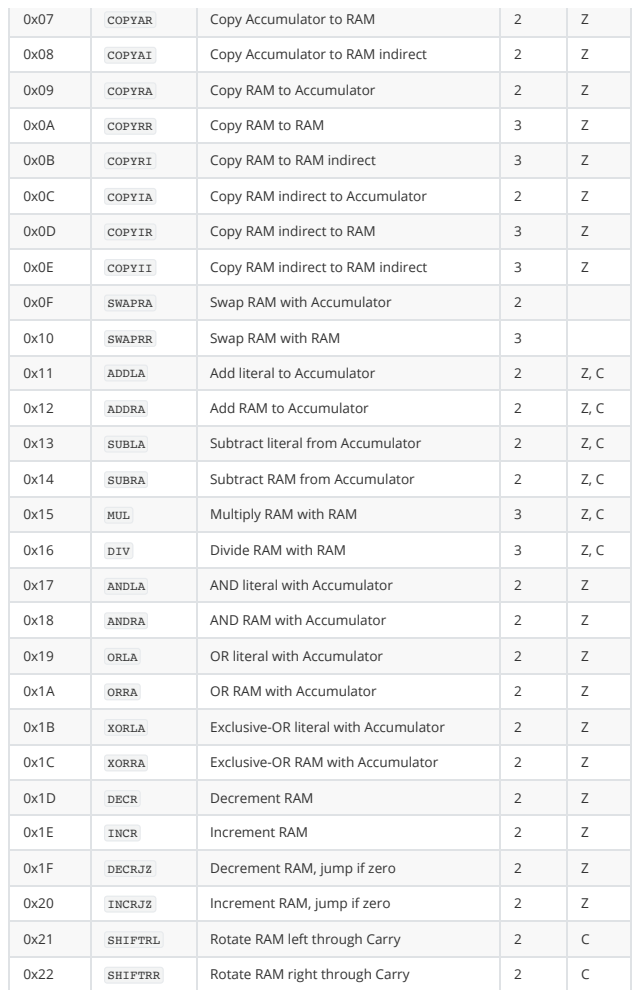
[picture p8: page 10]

0x07 | COPYAR | Copy Accumulator to RAM | 2 | Z

0x08 | COPYAI | Copy Accumulator to RAM indirect | 2 | Z

0x09 | COPYRA | Copy RAM to Accumulator | 2 | Z

0x0A | COPYRR | Copy RAM to RAM | 3 | Z

0x0B | COPYRI | Copy RAM to RAM indirect | 3 | Z

0x0C | COPYIA | Copy RAM indirect to Accumulator | 2 | Z

0x0D | COPYIR | Copy RAM indirect to RAM | 3 | Z

0x0E | COPYII | Copy RAM indirect to RAM indirect | 3 | Z

0x0F | SWAPRA | Swap RAM with Accumulator | 2

0x10 | SWAPRR | Swap RAM with RAM | 3

0x11 | ADDLA | Add literal to Accumulator | 2 | Z, C

0x12 | ADDRA | Add RAM to Accumulator | 2 | Z, C

0x13 | SUBLA | Subtract literal from Accumulator | 2 | Z, C

0x14 | SUBRA | Subtract RAM from Accumulator | 2 | Z, C

0x15 | MUL | Multiply RAM with RAM | 3 | Z, C

0x16 | DIV | Divide RAM with RAM | 3 | Z, C

0x17 | ANDLA | AND literal with Accumulator | 2 | Z

0x18 | ANDRA | AND RAM with Accumulator | 2 | Z

0x19 | ORLA | OR literal with Accumulator | 2 | Z

0x1A | ORRA | OR RAM with Accumulator | 2 | Z

0x1B | XORLA | Exclusive-OR literal with Accumulator | 2 | Z

0x1C | XORRA | Exclusive-OR RAM with Accumulator | 2 | Z

0x1D | DECR | Decrement RAM | 2 | Z

0x1E | INCR | Increment RAM | 2 | Z

0x1F | DECRJZ | Decrement RAM, jump if zero | 2 | Z

0x20 | INCRJZ | Increment RAM, jump if zero | 2 | Z

0x21 | SHIFTRL | Rotate RAM left through Carry | 2 | C

0x22 | SHIFTRR | Rotate RAM right through Carry | 2 | C

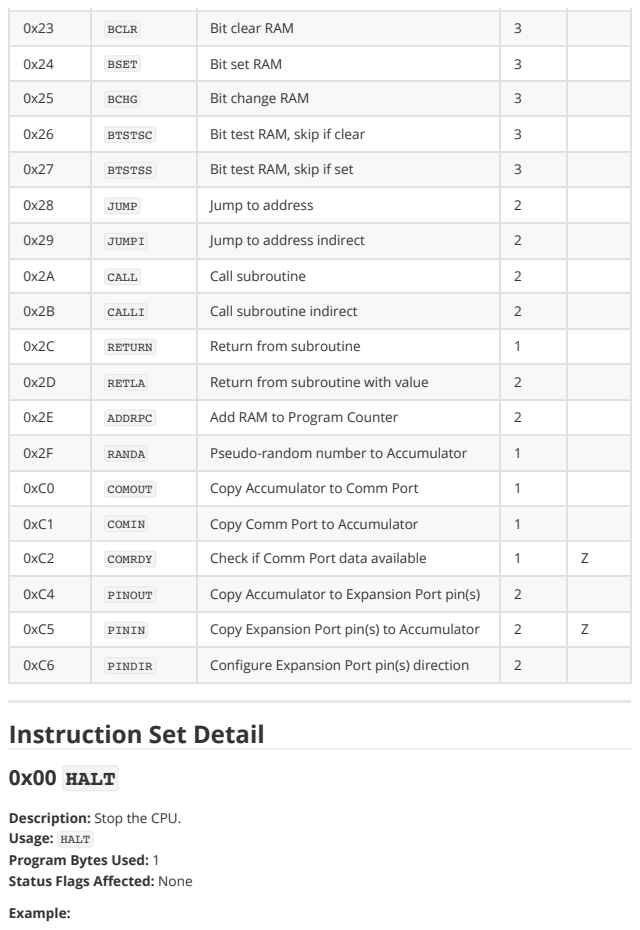
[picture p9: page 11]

0x23 | BCLR | Bit clear RAM | 3

0x24 | BSET | Bit set RAM | 3

0x25 | BCHG | Bit change RAM | 3

0x26 | BTSTSC | Bit test RAM, skip if clear | 3

0x27 | BTSTSS | Bit test RAM, skip if set | 3

0x28 | JUMP | Jump to address | 2

0x29 | JUMPI | Jump to address indirect | 2

0x2A | CALL | Call subroutine | 2

0x2B | CALLI | Call subroutine indirect | 2

0x2C | RETURN | Return from subroutine | 1

0x2D | RETLA | Return from subroutine with value | 2

0x2E | ADDRPC | Add RAM to Program Counter | 2

0x2F | RANDA | Pseudo-random number to Accumulator | 1

0xC0 | COMOUT | Copy Accumulator to Comm Port | 1

0xC1 | COMIN | Copy Comm Port to Accumulator | 1

0xC2 | COMRDY | Check if Comm Port data available | 1 | Z

0xC4 | PINOUT | Copy Accumulator to Expansion Port pin(s) | 2

0xC5 | PININ | Copy Expansion Port pin(s) to Accumulator | 2 | Z

0xC6 | PINDIR | Configure Expansion Port pin(s) direction | 2

Instruction Set Detail
0x00 HALT

Description: Stop the CPU.
Usage: HALT
Program Bytes Used: 1
Status Flags Affected: None
Example:

0x01 (00000001) | JUMP | 0x28 (00101000) | The Program Counter points here after HALT is executed
Value | mSec | Value | mSec | Value | mSec | Value | mSec
0x00 | 0 | 0x40 | 52 | 0x80 | 125 | 0xC0 | 250
0x01 | 1 | 0x41 | 53 | 0x81 | 127 | 0xC1 | 253

Tip: When the HALT instruction is executed, the Digirule 2U enters Stop mode, and any data written to the Address and/or Data LEDs registers by your program will no longer be displayed. If you want to effectively halt your program but keep your data displayed, use a JUMP * instruction instead.

Tip: It is sometimes helpful to follow a HALT instruction with a JUMP instruction to a restart point in your program, in case the Run/Stop button is pressed to resume execution.

## 0x01 NOP

Description: Performs no operation.
Usage: NOP
Program Bytes Used: 1

Description: Set the time interval at which the CPU executes instructions. The higher the value, the longer the interval (lower the rate).
Usage: SPEED value
Program Bytes Used: 2
Status Flags Affected: None

The following table shows the possible instruction argument values and the associated instruction execution intervals. For example, using a value of 0x80 (10000000) will result in the CPU executing one instruction every 125 milliseconds, or 8 instructions per second. Omitting this instruction, or using a value of 0x00 (00000000), will result in the CPU executing instructions at the maximum possible rate.

0x02 | 2 | 0x42 | 54 | 0x82 | 128 | 0xC2 | 256
0x03 | 3 | 0x43 | 55 | 0x83 | 130 | 0xC3 | 259
0x04 | 3 | 0x44 | 56 | 0x84 | 131 | 0xC4 | 262
0x05 | 4 | 0x45 | 57 | 0x85 | 133 | 0xC5 | 265
0x06 | 5 | 0x46 | 58 | 0x86 | 134 | 0xC6 | 268
0x07 | 5 | 0x47 | 59 | 0x87 | 136 | 0xC7 | 271
0x08 | 6 | 0x48 | 60 | 0x88 | 137 | 0xC8 | 275
0x09 | 7 | 0x49 | 61 | 0x89 | 139 | 0xC9 | 278
0x0A | 8 | 0x4A | 62 | 0x8A | 140 | 0xCA | 281
0x0B | 8 | 0x4B | 63 | 0x8B | 142 | 0xCB | 285
0x0C | 9 | 0x4C | 64 | 0x8C | 143 | 0xCC | 288
0x0D | 10 | 0x4D | 65 | 0x8D | 145 | 0xCD | 291
0x0E | 11 | 0x4E | 66 | 0x8E | 146 | 0xCE | 295
0x0F | 11 | 0x4F | 67 | 0x8F | 148 | 0xCF | 299
0x10 | 12 | 0x50 | 68 | 0x90 | 150 | 0xD0 | 302
0x11 | 13 | 0x51 | 69 | 0x91 | 151 | 0xD1 | 306
0x12 | 14 | 0x52 | 70 | 0x92 | 153 | 0xD2 | 310
0x13 | 14 | 0x53 | 71 | 0x93 | 154 | 0xD3 | 314
0x14 | 15 | 0x54 | 72 | 0x94 | 156 | 0xD4 | 318
0x15 | 16 | 0x55 | 73 | 0x95 | 158 | 0xD5 | 322
0x16 | 17 | 0x56 | 74 | 0x96 | 160 | 0xD6 | 326
0x17 | 17 | 0x57 | 75 | 0x97 | 161 | 0xD7 | 331
0x18 | 18 | 0x58 | 76 | 0x98 | 163 | 0xD8 | 335
0x19 | 19 | 0x59 | 78 | 0x99 | 165 | 0xD9 | 340
0x1A | 20 | 0x5A | 79 | 0x9A | 166 | 0xDA | 345
0x1B | 21 | 0x5B | 80 | 0x9B | 168 | 0xDB | 349
0x1C | 21 | 0x5C | 81 | 0x9C | 170 | 0xDC | 354
0x1D | 22 | 0x5D | 82 | 0x9D | 172 | 0xDD | 359
0x1E | 23 | 0x5E | 83 | 0x9E | 174 | 0xDE | 365
0x1F | 24 | 0x5F | 84 | 0x9F | 176 | 0xDF | 370
0x20 | 25 | 0x60 | 85 | 0xA0 | 177 | 0xE0 | 375
0x21 | 25 | 0x61 | 86 | 0xA1 | 179 | 0xE1 | 381
0x22 | 26 | 0x62 | 88 | 0xA2 | 181 | 0xE2 | 387
0x23 | 27 | 0x63 | 89 | 0xA3 | 183 | 0xE3 | 393

0x24 | 28 | 0x64 | 90 | 0xA4 | 185 | 0xE4 | 400
0x25 | 29 | 0x65 | 91 | 0xA5 | 187 | 0xE5 | 406
0x26 | 29 | 0x66 | 92 | 0xA6 | 189 | 0xE6 | 413
0x27 | 30 | 0x67 | 93 | 0xA7 | 191 | 0xE7 | 420
0x28 | 31 | 0x68 | 95 | 0xA8 | 193 | 0xE8 | 427
0x29 | 32 | 0x69 | 96 | 0xA9 | 195 | 0xE9 | 435
0x2A | 33 | 0x6A | 97 | 0xAA | 197 | 0xEA | 443
0x2B | 34 | 0x6B | 98 | 0xAB | 199 | 0xEB | 451
0x2C | 35 | 0x6C | 99 | 0xAC | 201 | 0xEC | 460
0x2D | 35 | 0x6D | 101 | 0xAD | 204 | 0xED | 470
0x2E | 36 | 0x6E | 102 | 0xAE | 206 | 0xEE | 479
0x2F | 37 | 0x6F | 103 | 0xAF | 208 | 0xEF | 490
0x30 | 38 | 0x70 | 104 | 0xB0 | 210 | 0xF0 | 500
0x31 | 39 | 0x71 | 106 | 0xB1 | 213 | 0xF1 | 512
0x32 | 40 | 0x72 | 107 | 0xB2 | 215 | 0xF2 | 525
0x33 | 41 | 0x73 | 108 | 0xB3 | 217 | 0xF3 | 538
0x34 | 41 | 0x74 | 109 | 0xB4 | 220 | 0xF4 | 552
0x35 | 42 | 0x75 | 111 | 0xB5 | 222 | 0xF5 | 568
0x36 | 43 | 0x76 | 112 | 0xB6 | 224 | 0xF6 | 585
0x37 | 44 | 0x77 | 113 | 0xB7 | 227 | 0xF7 | 604
0x38 | 45 | 0x78 | 115 | 0xB8 | 229 | 0xF8 | 625
0x39 | 46 | 0x79 | 116 | 0xB9 | 232 | 0xF9 | 650
0x3A | 47 | 0x7A | 117 | 0xBA | 234 | 0xFA | 677
0x3B | 48 | 0x7B | 119 | 0xBB | 237 | 0xFB | 710
0x3C | 49 | 0x7C | 120 | 0xBC | 240 | 0xFC | 750
0x3D | 50 | 0x7D | 121 | 0xBD | 242 | 0xFD | 802
0x3E | 51 | 0x7E | 123 | 0xBE | 245 | 0xFE | 875
0x3F | 51 | 0x7F | 124 | 0xBF | 248 | 0xFF | 1000

Example 1: Set the interval to 125 mS (8 instructions per second).

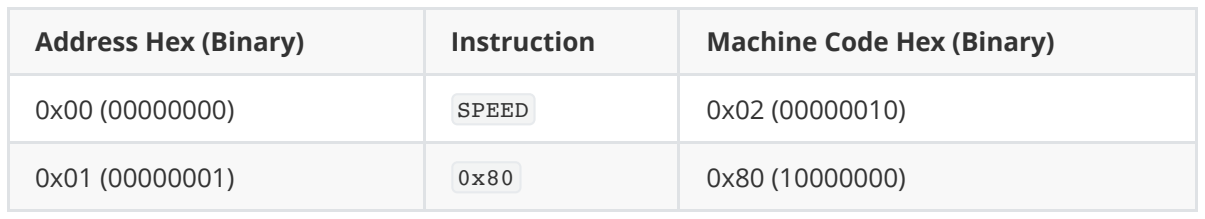
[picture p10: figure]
Address Hex (Binary); Instruction; Machine Code Hex (Binary); SPEED

Address Hex (Binary) | Instruction | Machine Code Hex (Binary)
0x00 (00000000) | SPEED | 0x02 (00000010)
0x01 (00000001) | 0xFF | 0xFF (11111111)
0x02 (00000010) | SPEED | 0x02 (00000010)
0x03 (00000011) | 0x00 | 0x00 (00000000)

Example 2: Set the interval to 10 mS (100 instructions per second).

Example 3: Perform a one-second time delay, then resume execution at the maximum rate.

### 0x03 INITSP

Description: Initialise the Stack Pointer to point to the top of the stack (i.e. empty the stack). Usage: INITSP
Program Bytes Used: 1

Tip: If your program uses the stack ( CALL / RETURN instructions), use of this instruction (typically near the beginning of your program) is recommended. If omitted, repeatedly restarting the program by simply resetting the Program Counter may eventually lead to a stack overflow condition.

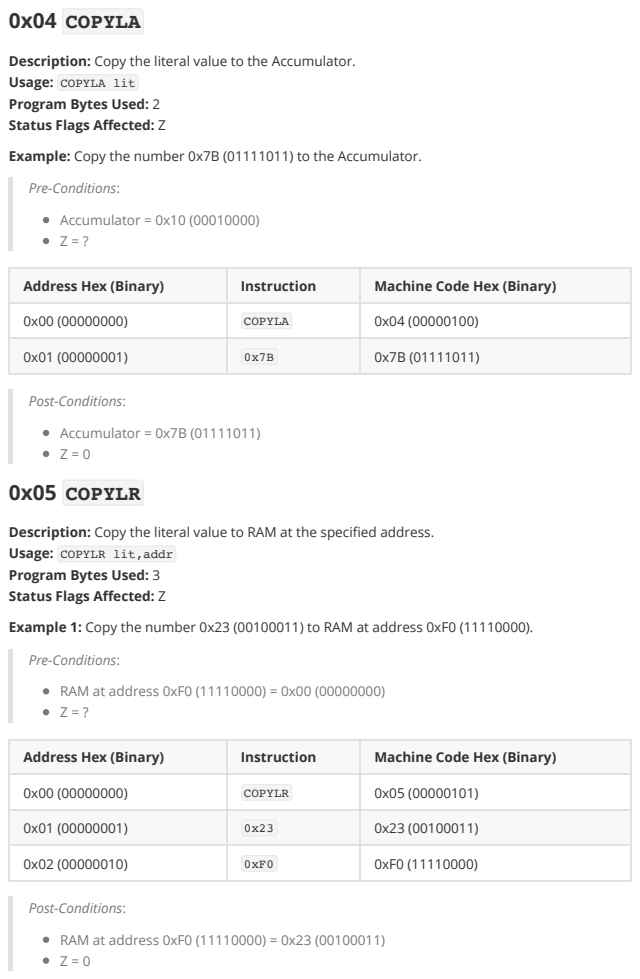
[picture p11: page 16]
0x04 COPYLA; Post-Conditions:; Accumulator = 0x7B (01111011) Z = 0; 0x05 COPYLR

Description: Copy the literal value to the Accumulator.
Usage: COPYLA lit
Program Bytes Used: 2
Status Flags Affected: Z
Example: Copy the number 0x7B (01111011) to the Accumulator.
Pre-Conditions:
Accumulator = 0x10 (00010000)

Address Hex (Binary) | Instruction | Machine Code Hex (Binary)

0x00 (00000000) | COPYLA | 0x04 (00000100)

Description: Copy the literal value to RAM at the specified address.
Usage: COPYLR lit,addr
Program Bytes Used: 3
Example 1: Copy the number 0x23 (00100011) to RAM at address 0xF0 (11110000).
RAM at address 0xF0 (11110000) = 0x00 (00000000)

0x00 (00000000) | COPYLR | 0x05 (00000101)

Post-Conditions:
RAM at address 0xF0 (11110000) = 0x23 (00100011)

Example 2: Copy the number 0x52 (01010010) to RAM at address 0xF1 (11110001).
Pre-Conditions:
RAM at address 0xF1 (11110001) = 0x0F (00001111)

Address Hex (Binary) | Instruction | Machine Code Hex (Binary)

0x00 (00000000) | COPYLR | 0x05 (00000101)

Post-Conditions:
RAM at address 0xF1 (11110001) = 0x52 (01010010)
0x06 COPYLI

Description: Copy the literal value to RAM at the address contained in RAM at the specified
address.
Usage: COPYLI lit,addr
Program Bytes Used: 3
Status Flags Affected: Z
Example: Copy the number 0x17 (00010111) to RAM through the pointer at address 0xE0
RAM at address 0xE0 (11100000) = 0x20 (00100000)
RAM at address 0x20 (00100000) = 0x00 (00000000)

0x00 (00000000) | COPYLI | 0x06 (00000110)

RAM at address 0x20 (00100000) = 0x17 (00010111)

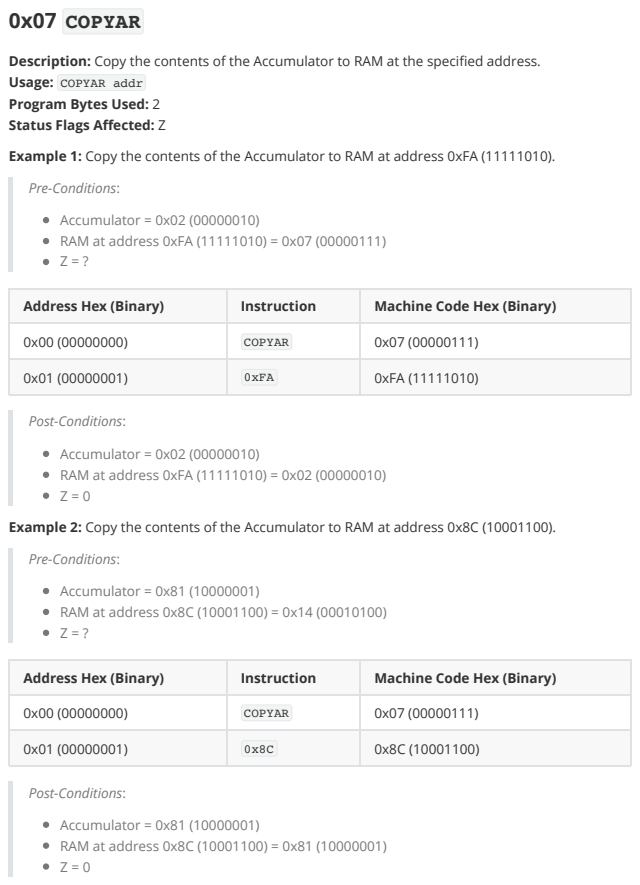
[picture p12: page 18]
0x07 COPYAR

Description: Copy the contents of the Accumulator to RAM at the specified address.
Usage: COPYAR addr
Program Bytes Used: 2
Status Flags Affected: Z
Example 1: Copy the contents of the Accumulator to RAM at address 0xFA (11111010).
Pre-Conditions:
Accumulator = 0x02 (00000010)
RAM at address 0xFA (11111010) = 0x07 (00000111)

Address Hex (Binary) | Instruction | Machine Code Hex (Binary)

0x00 (00000000) | COPYAR | 0x07 (00000111)

0x01 (00000001) | 0xFA | 0xFA (11111010)

Post-Conditions:
RAM at address 0xFA (11111010) = 0x02 (00000010)
Example 2: Copy the contents of the Accumulator to RAM at address 0x8C (10001100).
Accumulator = 0x81 (10000001)
RAM at address 0x8C (10001100) = 0x14 (00010100)

RAM at address 0x8C (10001100) = 0x81 (10000001)

### 0x08 COPYAI

Description: Copy the contents of the Accumulator to RAM at the address contained in RAM at the specified address.
Usage: COPYAI addr
Program Bytes Used: 2
Status Flags Affected: Z

Example: Copy the contents of the Accumulator to RAM through the pointer at address 0xC0

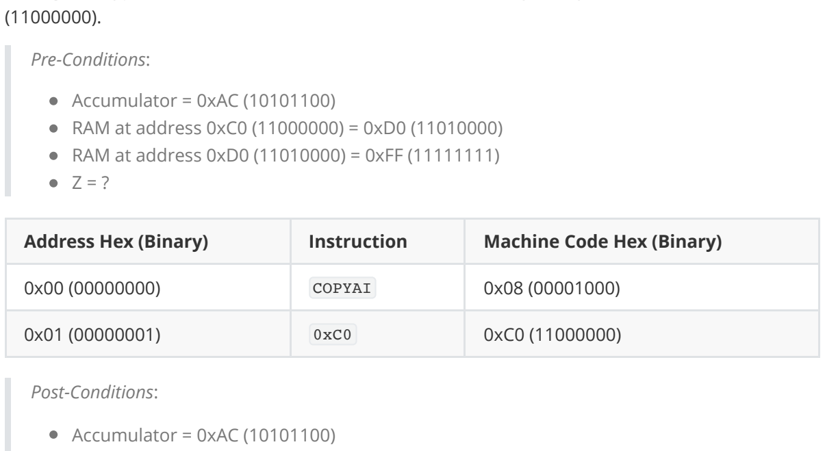
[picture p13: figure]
Address Hex (Binary); Instruction; Machine Code Hex (Binary); COPYAI; Pre-Conditions:; Accumulator = 0xAC (10101100); Post-Conditions:

RAM at address 0xC0 (11000000) = 0xD0 (11010000) RAM at address 0xD0 (11010000) = 0xFF (11111111)

RAM at address 0xC0 (11000000) = 0xD0 (11010000) RAM at address 0xD0 (11010000) = 0xAC (10101100) Z = 0

### 0x09 COPYRA

Description: Copy the contents of RAM at the specified address to the Accumulator.
Usage: COPYRA addr
Program Bytes Used: 2
Status Flags Affected: Z

Example 1: Copy the contents of RAM at address 0xF3 (11110011) to the Accumulator.

Pre-Conditions:

RAM at address 0xF3 (11110011) = 0x7F (01111111)
Accumulator = 0x10 (00010000)
Z = ?

Address Hex (Binary) | Instruction | Machine Code Hex (Binary)

0x00 (00000000) | COPYRA | 0x09 (00001001)

Post-Conditions:
RAM at address 0xF3 (11110011) = 0x7F (01111111)
Accumulator = 0x7F (01111111)
Example 2: Copy the contents of RAM at address 0x8C (10001100) to the Accumulator.
Pre-Conditions:
RAM at address 0x8C (10001100) = 0x20 (00100000)
Accumulator = 0x38 (00111000)

Description: Copy the contents of RAM at the specified source address to RAM at the specified
destination address.
Usage: COPYRR src_addr,dst_addr
Program Bytes Used: 3
Status Flags Affected: Z
Example 1: Copy the contents of RAM at address 0xF0 (11110000) to RAM at address 0xF1
RAM at address 0xF0 (11110000) = 0x0A (00001010)
RAM at address 0xF1 (11110001) = 0x00 (00000000)

RAM at address 0xF0 (11110000) = 0x0A (00001010)
RAM at address 0xF1 (11110001) = 0x0A (00001010)
Z = 0

Example 2: Copy the contents of RAM at address 0xF5 (11110101) to RAM at address 0xF4

RAM at address 0xF5 (11110101) = 0x00 (00000000)
RAM at address 0xF4 (11110100) = 0x19 (00011001)

RAM at address 0xF5 (11110101) = 0x00 (00000000) RAM at address 0xF4 (11110100) = 0x00 (00000000) Z = 1

### 0x0B COPYRI

Description: Copy the contents of RAM at the specified source address to RAM at the address contained in RAM at the specified destination address.
Usage: COPYRI src_addr,dst_addr
Program Bytes Used: 3
Status Flags Affected: Z

Example: Copy the contents of RAM at address 0xB0 (10110000) to RAM through the pointer at address 0xC0 (11000000).

Pre-Conditions:

RAM at address 0xB0 (10110000) = 0x45 (01000101)
RAM at address 0xC0 (11000000) = 0xD0 (11010000)

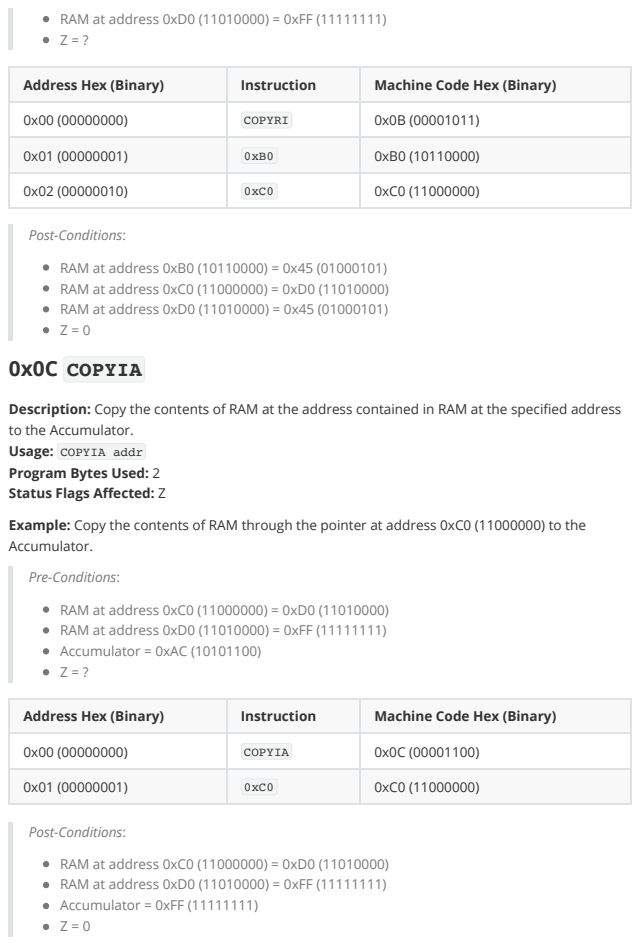
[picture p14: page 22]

RAM at address 0xD0 (11010000) = 0xFF (11111111)

Address Hex (Binary) | Instruction | Machine Code Hex (Binary)

0x00 (00000000) | COPYRI | 0x0B (00001011)

Post-Conditions:
RAM at address 0xB0 (10110000) = 0x45 (01000101)
RAM at address 0xC0 (11000000) = 0xD0 (11010000)
RAM at address 0xD0 (11010000) = 0x45 (01000101)
0x0C COPYIA

Description: Copy the contents of RAM at the address contained in RAM at the specified address
to the Accumulator.
Usage: COPYIA addr
Program Bytes Used: 2
Status Flags Affected: Z
Example: Copy the contents of RAM through the pointer at address 0xC0 (11000000) to the
Accumulator.
Pre-Conditions:
Accumulator = 0xAC (10101100)

0x00 (00000000) | COPYIA | 0x0C (00001100)

Accumulator = 0xFF (11111111)

### 0x0D COPYIR

Description: Copy the contents of RAM at the address contained in RAM at the specified source address to RAM at the specified destination address.
Usage: COPYIR src_addr,dst_addr
Program Bytes Used: 3
Status Flags Affected: Z

Example: Copy the contents of RAM through the pointer at address 0xC0 (11000000) to RAM at

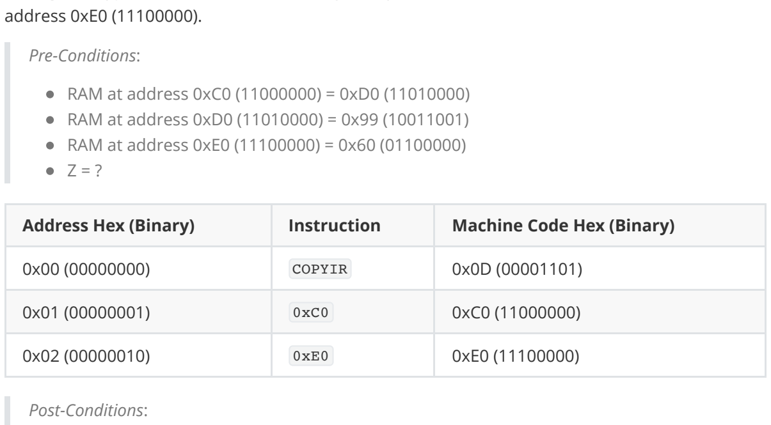
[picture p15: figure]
Address Hex (Binary); Instruction; Machine Code Hex (Binary); COPYIR; address 0xE0 (11100000).; Pre-Conditions:; Post-Conditions:

RAM at address 0xC0 (11000000) = 0xD0 (11010000)
RAM at address 0xD0 (11010000) = 0x99 (10011001) RAM at address 0xE0 (11100000) = 0x60 (01100000)

RAM at address 0xC0 (11000000) = 0xD0 (11010000) RAM at address 0xD0 (11010000) = 0x99 (10011001) RAM at address 0xE0 (11100000) = 0x99 (10011001) Z = 0

### 0x0E COPYII

Description: Copy the contents of RAM at the address contained in RAM at the specified source address to RAM at the address contained in RAM at the specified destination address.
Usage: COPYII src_addr,dst_addr
Program Bytes Used: 3
Status Flags Affected: Z

Example: Copy the contents of RAM through the pointer at address 0xC0 (11000000) to RAM through the pointer at address 0xE0 (11100000).

Pre-Conditions:

RAM at address 0xC0 (11000000) = 0xD0 (11010000)
RAM at address 0xD0 (11010000) = 0x18 (00011000) RAM at address 0xE0 (11100000) = 0xF0 (11110000) RAM at address 0xF0 (11110000) = 0x81 (10000001) Z = ?

RAM at address 0xC0 (11000000) = 0xD0 (11010000) RAM at address 0xD0 (11010000) = 0x18 (00011000) RAM at address 0xE0 (11100000) = 0xF0 (11110000) RAM at address 0xF0 (11110000) = 0x18 (00011000) Z = 0

### 0x0F SWAPRA

Description: Swap the contents of RAM at the specified address with the contents of the Accumulator.
Usage: SWAPRA addr
Program Bytes Used: 2
Status Flags Affected: None

Example: Swap the contents of RAM at address 0x10 (00010000) with the contents of the

RAM at address 0x10 (00010000) = 0xAA (10101010)

RAM at address 0x10 (00010000) = 0x55 (01010101) Accumulator = 0xAA (10101010)

### 0x10 SWAPRR

Description: Swap the contents of RAM at the specified source address with the contents of RAM at the specified destination address.
Usage: SWAPRR src_addr,dst_addr
Program Bytes Used: 3
Status Flags Affected: None

Example: Swap the contents of RAM at address 0x10 (00010000) with the contents of RAM at
address 0x20 (00100000).
Pre-Conditions:
RAM at address 0x10 (00010000) = 0x0D (00001101)
RAM at address 0x20 (00100000) = 0x0A (00001010)

Address Hex (Binary) | Instruction | Machine Code Hex (Binary)

0x00 (00000000) | SWAPRR | 0x10 (00010000)

Post-Conditions:
RAM at address 0x10 (00010000) = 0x0A (00001010)
RAM at address 0x20 (00100000) = 0x0D (00001101)
0x11 ADDLA

Description: Add the literal value and the Carry flag to the Accumulator.
Usage: ADDLA lit
Program Bytes Used: 2
Status Flags Affected: Z, C
Example 1: Add the literal value 0x0F (00001111) to the Accumulator.
Accumulator = 0x00 (00000000)

0x00 (00000000) | ADDLA | 0x11 (00010001)

Accumulator = 0x0F (00001111)
Example 2: Add the literal value 0x01 (00000001) to the Accumulator.

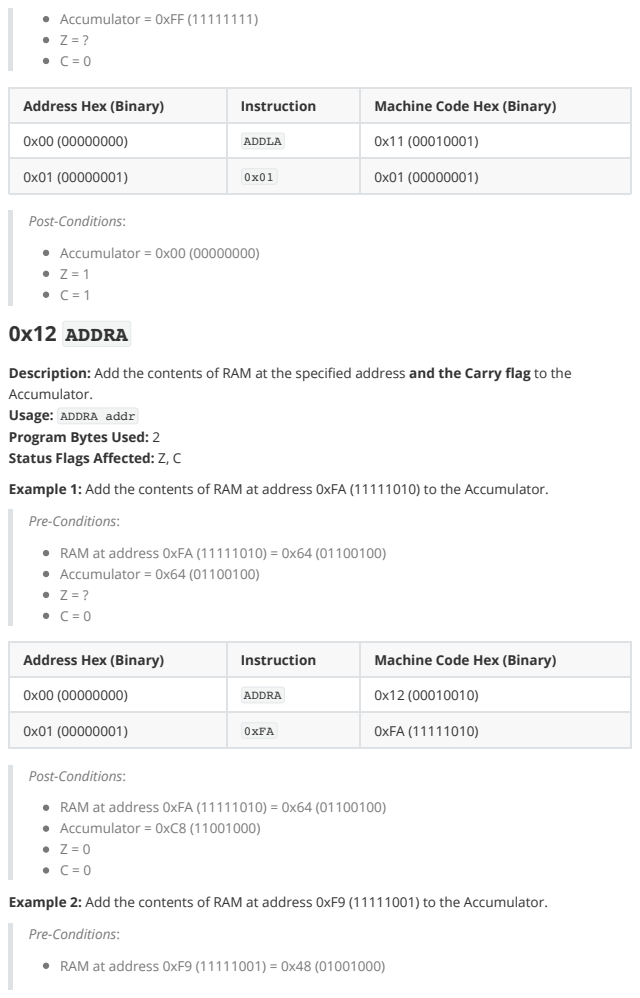
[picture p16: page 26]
Accumulator = 0xFF (11111111) Z = ? C = 0; Post-Conditions:; Accumulator = 0x00 (00000000) Z = 1 C = 1; 0x12 ADDRA

Address Hex (Binary) | Instruction | Machine Code Hex (Binary)

0x00 (00000000) | ADDLA | 0x11 (00010001)

Description: Add the contents of RAM at the specified address and the Carry flag to the
Accumulator.
Usage: ADDRA addr
Program Bytes Used: 2
Status Flags Affected: Z, C
Example 1: Add the contents of RAM at address 0xFA (11111010) to the Accumulator.
Pre-Conditions:
RAM at address 0xFA (11111010) = 0x64 (01100100)
Accumulator = 0x64 (01100100)

0x00 (00000000) | ADDRA | 0x12 (00010010)

0x01 (00000001) | 0xFA | 0xFA (11111010)

Post-Conditions:
Accumulator = 0xC8 (11001000)
Example 2: Add the contents of RAM at address 0xF9 (11111001) to the Accumulator.
RAM at address 0xF9 (11111001) = 0x48 (01001000)

Address Hex (Binary) | Instruction | Machine Code Hex (Binary)

0x00 (00000000) | ADDRA | 0x12 (00010010)

Description: Subtract the literal value and the Carry flag from the Accumulator.
Usage: SUBLA lit
Program Bytes Used: 2
Status Flags Affected: Z, C
Example 1: Subtract the literal value 0x14 (00010100) from the Accumulator.
Pre-Conditions:
Accumulator = 0x14 (00010100)

0x00 (00000000) | SUBLA | 0x13 (00010011)

Post-Conditions:
Accumulator = 0x00 (00000000)
Example 2: Subtract the literal value 0x29 (00101001) from the Accumulator.
Accumulator = 0x28 (00101000)

Address Hex (Binary) | Instruction | Machine Code Hex (Binary)

0x00 (00000000) | SUBLA | 0x13 (00010011)

Description: Subtract the contents of RAM at the specified address and the Carry flag from the
Accumulator.
Usage: SUBRA addr
Program Bytes Used: 2
Status Flags Affected: Z, C
Example 1: Subtract the contents of RAM at address 0xFA (11111010) from the Accumulator.
Pre-Conditions:
RAM at address 0xFA (11111010) = 0x22 (00100010)
Accumulator = 0xC9 (11001001)

0x00 (00000000) | SUBRA | 0x14 (00010100)

0x01 (00000001) | 0xFA | 0xFA (11111010)

Post-Conditions:
Accumulator = 0xA7 (10100111)
Example 2: Subtract the contents of RAM at address 0xF5 (11110101) from the Accumulator.
RAM at address 0xF5 (11110101) = 0xFF (11111111)
Accumulator = 0xFF (11111111)

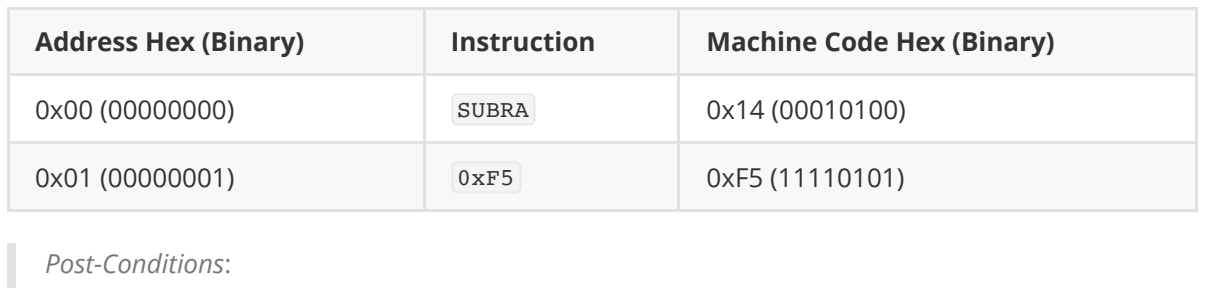
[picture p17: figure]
Address Hex (Binary); Instruction; Machine Code Hex (Binary); SUBRA; Post-Conditions:

RAM at address 0xF5 (11110101) = 0xFF (11111111) Accumulator = 0x00 (00000000)
Z = 1
C = 0

## 0x15 MUL

Description: Multiply the contents of RAM at the first specified address (multiplicand) by the contents of RAM at the second specified address (multiplier). Store the product in RAM at the first specified address.
Usage: MUL multiplicand_product_addr,multiplier_addr
Program Bytes Used: 3
Status Flags Affected: Z, C

Example 1: Multiply the contents of RAM at address 0xC0 (11000000) by the contents of RAM at

RAM at address 0xC0 (11000000) = 0x0F (00001111)
RAM at address 0xC1 (11000001) = 0x0A (00001010)

RAM at address 0xC0 (11000000) = 0x96 (10010110) RAM at address 0xC1 (11000001) = 0x0A (00001010)
Z = 0
C = 0

Example 2: Multiply the contents of RAM at address 0xC0 (11000000) by the contents of RAM at address 0xC1 (11000001).

Pre-Conditions:

RAM at address 0xC0 (11000000) = 0x20 (00100000)

RAM at address 0xC1 (11000001) = 0x08 (00001000)

RAM at address 0xC0 (11000000) = 0x00 (00000000) RAM at address 0xC1 (11000001) = 0x08 (00001000) Z = 1
C = 1

## 0x16 DIV

Description: Divide the contents of RAM at the first specified address (dividend) by the contents of RAM at the second specified address (divisor). Store the quotient in RAM at the first specified address. Store the remainder in the Accumulator. The Z flag reflects the zero status of the quotient, and the C flag reflects the zero status of the remainder.
Usage: DIV dividend_quotient_addr,divisor_addr
Program Bytes Used: 3
Status Flags Affected: Z, C

Example 1: Divide the contents of RAM at address 0xC0 (11000000) by the contents of RAM at address 0xC1 (11000001).

Pre-Conditions:

RAM at address 0xC0 (11000000) = 0xFF (11111111)

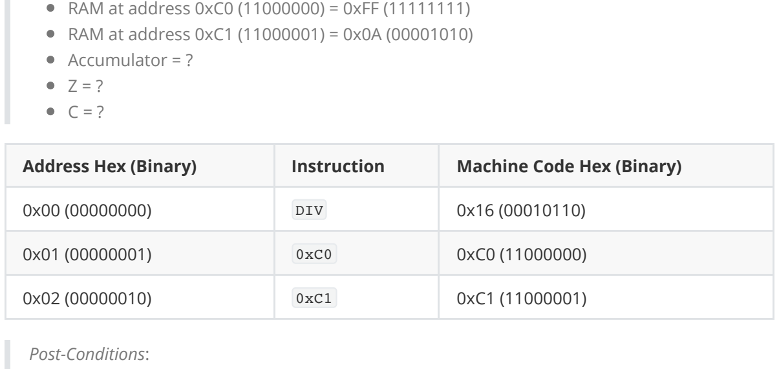
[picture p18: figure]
Address Hex (Binary); Instruction; Machine Code Hex (Binary); DIV; Accumulator = ? Z = ? C = ?; Post-Conditions:

RAM at address 0xC1 (11000001) = 0x0A (00001010)

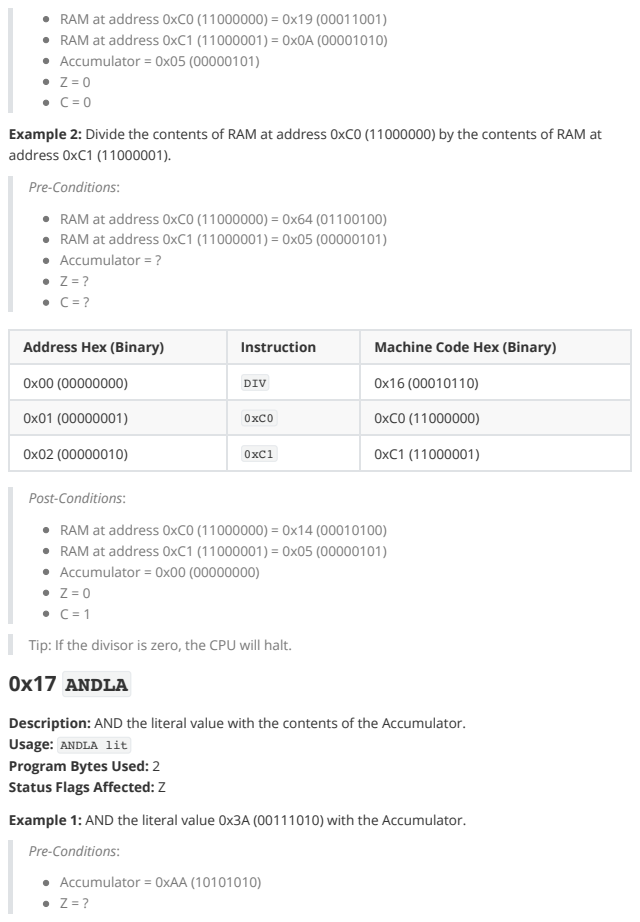
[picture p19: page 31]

RAM at address 0xC0 (11000000) = 0x19 (00011001)
RAM at address 0xC1 (11000001) = 0x0A (00001010)
Accumulator = 0x05 (00000101)
Example 2: Divide the contents of RAM at address 0xC0 (11000000) by the contents of RAM at
address 0xC1 (11000001).
Pre-Conditions:
RAM at address 0xC0 (11000000) = 0x64 (01100100)
RAM at address 0xC1 (11000001) = 0x05 (00000101)
Accumulator = ?

Address Hex (Binary) | Instruction | Machine Code Hex (Binary)

0x00 (00000000) | DIV | 0x16 (00010110)

Post-Conditions:
RAM at address 0xC0 (11000000) = 0x14 (00010100)
Accumulator = 0x00 (00000000)
Tip: If the divisor is zero, the CPU will halt.
0x17 ANDLA

Description: AND the literal value with the contents of the Accumulator.
Usage: ANDLA lit
Program Bytes Used: 2
Status Flags Affected: Z
Example 1: AND the literal value 0x3A (00111010) with the Accumulator.
Accumulator = 0xAA (10101010)

Address Hex (Binary) | Instruction | Machine Code Hex (Binary)

0x00 (00000000) | ANDLA | 0x17 (00010111)

Post-Conditions:
Accumulator = 0x2A (00101010)
Example 2: AND the literal value 0x63 (01100011) with the Accumulator.
Pre-Conditions:
Accumulator = 0x9C (10011100)

Description: AND the contents of RAM at the specified address with the Accumulator.
Usage: ANDRA addr
Program Bytes Used: 2
Status Flags Affected: Z
Example 1: AND the contents of RAM at address 0xF0 (11110000) with the Accumulator.
RAM at address 0xF0 (11110000) = 0x10 (00010000)
Accumulator = 0x30 (00110000)

0x00 (00000000) | ANDRA | 0x18 (00011000)

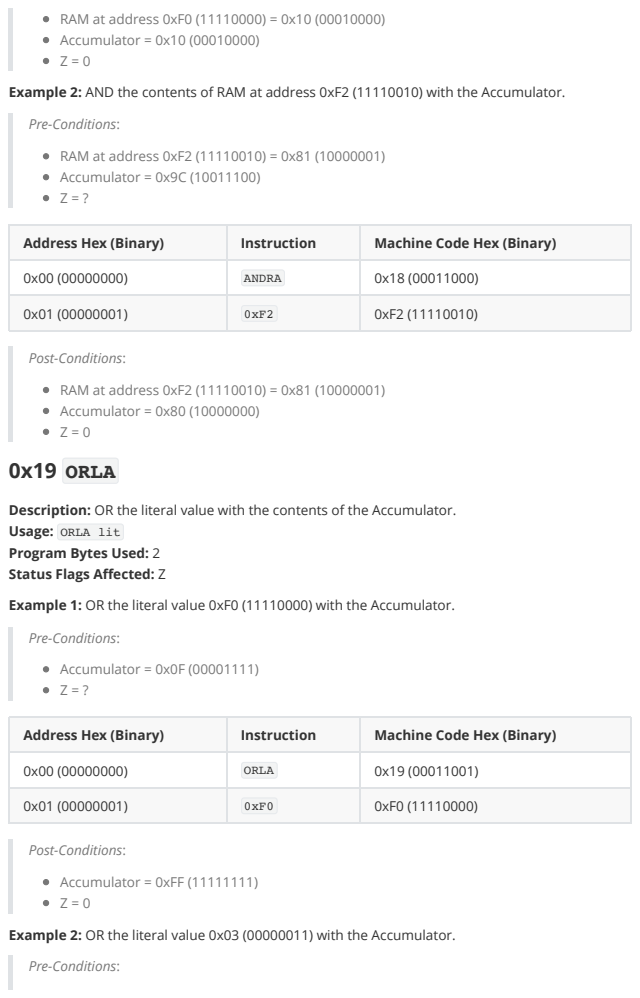
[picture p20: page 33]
Post-Conditions:; RAM at address 0xF2 (11110010) = 0x81 (10000001) Accumulator = 0x80 (10000000) Z = 0 0x19 ORLA

RAM at address 0xF0 (11110000) = 0x10 (00010000)
Accumulator = 0x10 (00010000)
Example 2: AND the contents of RAM at address 0xF2 (11110010) with the Accumulator.
Pre-Conditions:
RAM at address 0xF2 (11110010) = 0x81 (10000001)
Accumulator = 0x9C (10011100)

Address Hex (Binary) | Instruction | Machine Code Hex (Binary)

0x00 (00000000) | ANDRA | 0x18 (00011000)

Description: OR the literal value with the contents of the Accumulator.
Usage: ORLA lit
Program Bytes Used: 2
Status Flags Affected: Z
Example 1: OR the literal value 0xF0 (11110000) with the Accumulator.
Accumulator = 0x0F (00001111)

0x00 (00000000) | ORLA | 0x19 (00011001)

Post-Conditions:
Accumulator = 0xFF (11111111)
Example 2: OR the literal value 0x03 (00000011) with the Accumulator.

Address Hex (Binary) | Instruction | Machine Code Hex (Binary)

0x00 (00000000) | ORLA | 0x19 (00011001)

Description: OR the contents of RAM at the specified address with the Accumulator.
Usage: ORRA addr
Program Bytes Used: 2
Status Flags Affected: Z
Example 1: OR the contents of RAM at address 0xF1 (11110001) with the Accumulator.
Pre-Conditions:
RAM at address 0xF1 (11110001) = 0x81 (10000001)
Accumulator = 0x0C (00001100)

0x00 (00000000) | ORRA | 0x1A (00011010)

Post-Conditions:
Accumulator = 0x8D (10001101)
Example 2: OR the contents of RAM at address 0xF9 (11111001) with the Accumulator.
RAM at address 0xF9 (11111001) = 0x09 (00001001)
Accumulator = 0x01 (00000001)

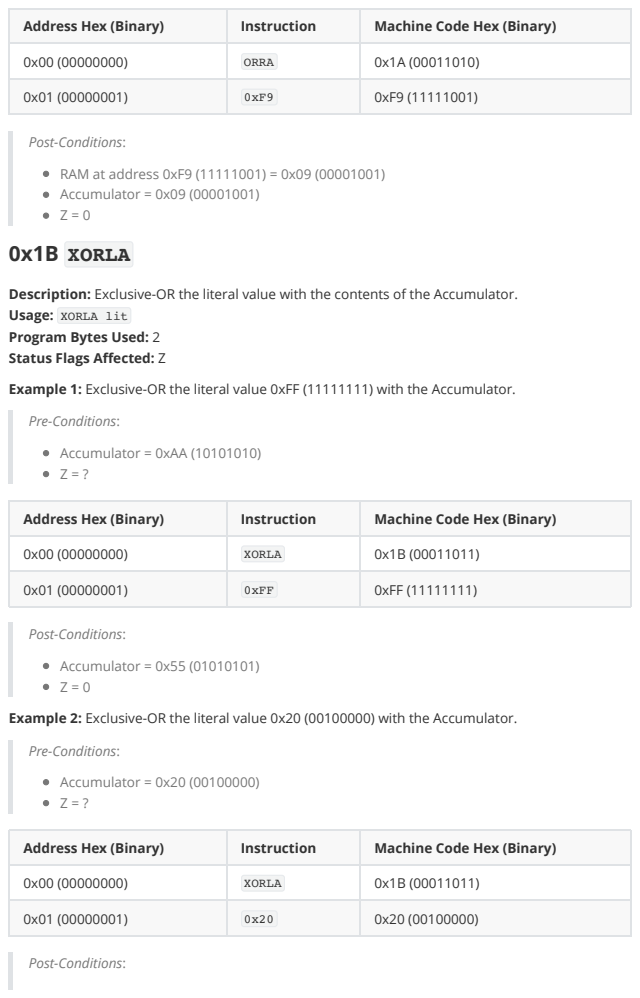
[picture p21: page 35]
Post-Conditions:; RAM at address 0xF9 (11111001) = 0x09 (00001001) Accumulator = 0x09 (00001001) Z = 0; 0x1B XORLA

Address Hex (Binary) | Instruction | Machine Code Hex (Binary)

0x00 (00000000) | ORRA | 0x1A (00011010)

Description: Exclusive-OR the literal value with the contents of the Accumulator.
Usage: XORLA lit
Program Bytes Used: 2
Status Flags Affected: Z
Example 1: Exclusive-OR the literal value 0xFF (11111111) with the Accumulator.
Pre-Conditions:
Accumulator = 0xAA (10101010)

0x00 (00000000) | XORLA | 0x1B (00011011)

0x01 (00000001) | 0xFF | 0xFF (11111111)

Post-Conditions:
Accumulator = 0x55 (01010101)
Example 2: Exclusive-OR the literal value 0x20 (00100000) with the Accumulator.
Accumulator = 0x20 (00100000)

Description: Exclusive-OR the contents of RAM at the specified address with the Accumulator.
Usage: XORRA addr
Program Bytes Used: 2
Status Flags Affected: Z
Example 1: Exclusive-OR the contents of RAM at address 0xF5 (11110101) with the Accumulator.
Pre-Conditions:
RAM at address 0xF5 (11110101) = 0x09 (00001001)
Accumulator = 0x0F (00001111)

Address Hex (Binary) | Instruction | Machine Code Hex (Binary)

0x00 (00000000) | XORRA | 0x1C (00011100)

Post-Conditions:
Accumulator = 0x06 (00000110)
Example 2: Exclusive-OR the contents of RAM at address 0xFA (11111010) with the Accumulator.
RAM at address 0xFA (11111010) = 0xFF (11111111)
Accumulator = 0x15 (00010101)

0x01 (00000001) | 0xFA | 0xFA (11111010)

Accumulator = 0xEA (11101010)

## 0x1D DECR

Description: Decrement the contents of RAM at the specified address.
Usage: DECR addr
Program Bytes Used: 2
Status Flags Affected: Z

Example 1: Decrement the contents of RAM at address 0xF8 (11111000).

RAM at address 0xF8 (11111000) = 0x2B (00101011)

RAM at address 0xF8 (11111000) = 0x2A (00101010)
Z = 0

Example 2: Decrement the contents of RAM at address 0xF1 (11110001).

RAM at address 0xF1 (11110001) = 0x01 (00000001)

RAM at address 0xF1 (11110001) = 0x00 (00000000) Z = 1

## 0x1E INCR

Description: Increment the contents of RAM at the specified address.
Usage: INCR addr
Program Bytes Used: 2
Status Flags Affected: Z

Example 1: Increment the contents of RAM at address 0xF8 (11111000).

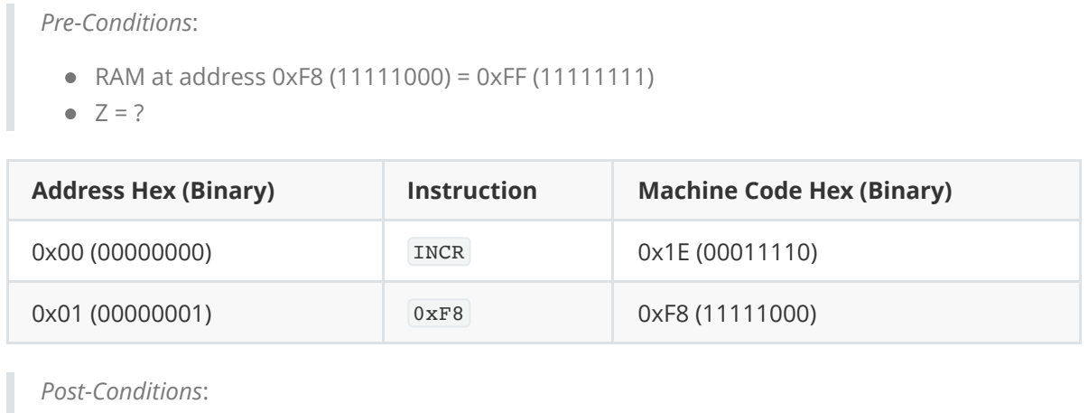
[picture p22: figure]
Address Hex (Binary); Instruction; Machine Code Hex (Binary); INCR; Pre-Conditions:; Post-Conditions:

RAM at address 0xF8 (11111000) = 0xFF (11111111)

RAM at address 0xF8 (11111000) = 0x00 (00000000)
Z = 1

Example 2: Increment the contents of RAM at address 0xF1 (11110001).

RAM at address 0xF1 (11110001) = 0x01 (00000001)

RAM at address 0xF1 (11110001) = 0x02 (00000010) Z = 0

### 0x1F DECRJZ

Description: Decrement the contents of RAM at the specified address. If the result is zero, advance the Program Counter by two.
Usage: DECRJZ addr
Program Bytes Used: 2
Status Flags Affected: Z

Example 1: Decrement the contents of RAM at address 0xFA (11111010). Since the result is not zero, execution continues with the JUMP instruction.

Pre-Conditions:

RAM at address 0xFA (11111010) = 0x05 (00000101)
Z = ?

Address Hex (Binary) | Instruction | Machine Code Hex (Binary)
0x00 (00000000) | DECRJZ | 0x1F (00011111)
0x01 (00000001) | 0xFA | 0xFA (11111010)
0x02 (00000010) | JUMP | 0x28 (00101000)
0x03 (00000011) | 0x00 | 0x00 (00000000)
0x04 (00000100) | HALT | 0x00 (00000000)
Address Hex (Binary) | Instruction | Machine Code Hex (Binary)
0x00 (00000000) | DECRJZ | 0x1F (00011111)
0x01 (00000001) | 0xFA | 0xFA (11111010)
0x02 (00000010) | JUMP | 0x28 (00101000)
0x03 (00000011) | 0x00 | 0x00 (00000000)
0x04 (00000100) | HALT | 0x00 (00000000)

Post-Conditions:

RAM at address 0xFA (11111010) = 0x04 (00000100)
Z = 0

Example 2: Decrement the contents of RAM at address 0xFA (11111010). Since the result is zero, execution continues with the HALT instruction.

Pre-Conditions:

RAM at address 0xFA (11111010) = 0x01 (00000001)
Z = ?

Post-Conditions:

RAM at address 0xFA (11111010) = 0x00 (00000000) Z = 1

### 0x20 INCRJZ

Description: Increment the contents of RAM at the specified address. If the result is zero, advance the Program Counter by two.
Usage: INCRJZ addr
Program Bytes Used: 2
Status Flags Affected: Z

Example 1: Increment the contents of RAM at address 0xFB (11111011). Since the result is not zero, execution continues with the JUMP instruction.

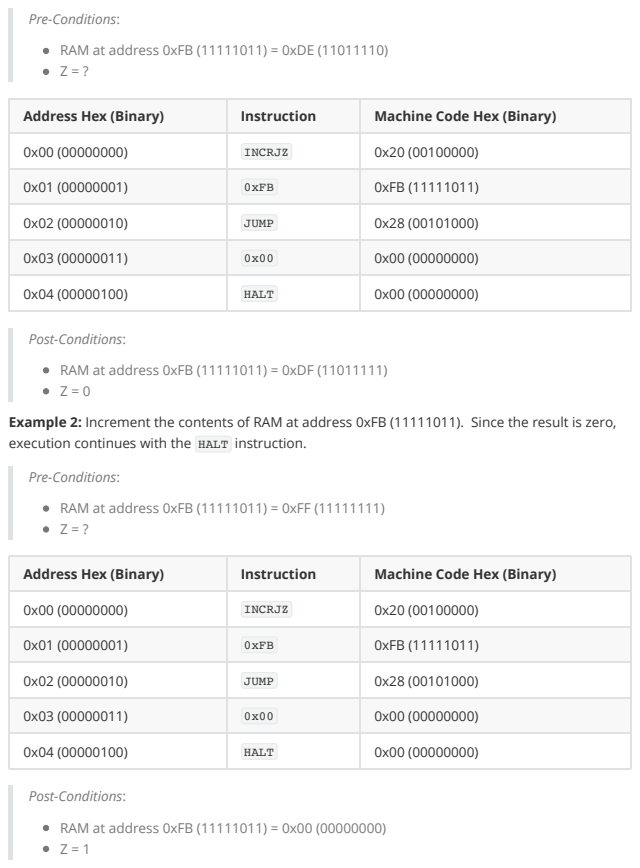
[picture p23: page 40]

Pre-Conditions:
RAM at address 0xFB (11111011) = 0xDE (11011110)

Address Hex (Binary) | Instruction | Machine Code Hex (Binary)

0x00 (00000000) | INCRJZ | 0x20 (00100000)

0x01 (00000001) | 0xFB | 0xFB (11111011)

0x02 (00000010) | JUMP | 0x28 (00101000)

0x04 (00000100) | HALT | 0x00 (00000000)

Post-Conditions:
RAM at address 0xFB (11111011) = 0xDF (11011111)
Example 2: Increment the contents of RAM at address 0xFB (11111011). Since the result is zero,
execution continues with the HALT instruction.
RAM at address 0xFB (11111011) = 0xFF (11111111)

RAM at address 0xFB (11111011) = 0x00 (00000000)

### 0x21 SHIFTRL

Description: Shift (rotate) left through Carry the contents of RAM at the specified address.
Usage: SHIFTRL addr
Program Bytes Used: 2
Status Flags Affected: C

Example 1: Shift left through Carry the contents of RAM at address 0xF1 (11110001).

RAM at address 0xF1 (11110001) = 0x55 (01010101)

RAM at address 0xF1 (11110001) = 0xAB (10101011)
C = 0

Example 2: Shift left through Carry the contents of RAM at address 0xF1 (11110001).

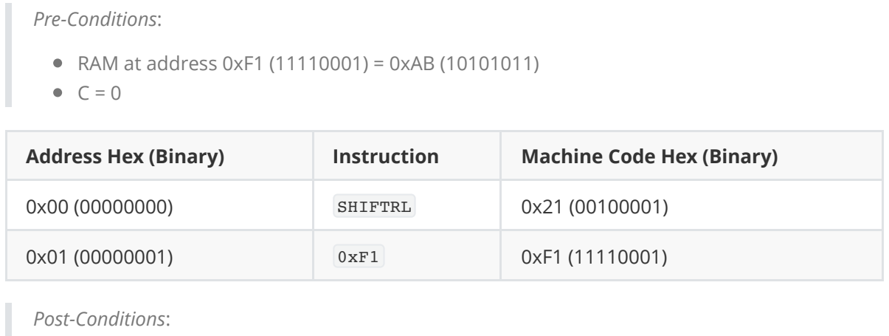
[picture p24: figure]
Address Hex (Binary); Instruction; Machine Code Hex (Binary); SHIFTRL; Pre-Conditions:; Post-Conditions:

RAM at address 0xF1 (11110001) = 0xAB (10101011)

RAM at address 0xF1 (11110001) = 0x56 (01010110) C = 1

### 0x22 SHIFTRR

Description: Shift (rotate) right through Carry the contents of RAM at the specified address.
Usage: SHIFTRR addr
Program Bytes Used: 2
Status Flags Affected: C

Example 1: Shift right through Carry the contents of RAM at address 0xF1 (11110001).

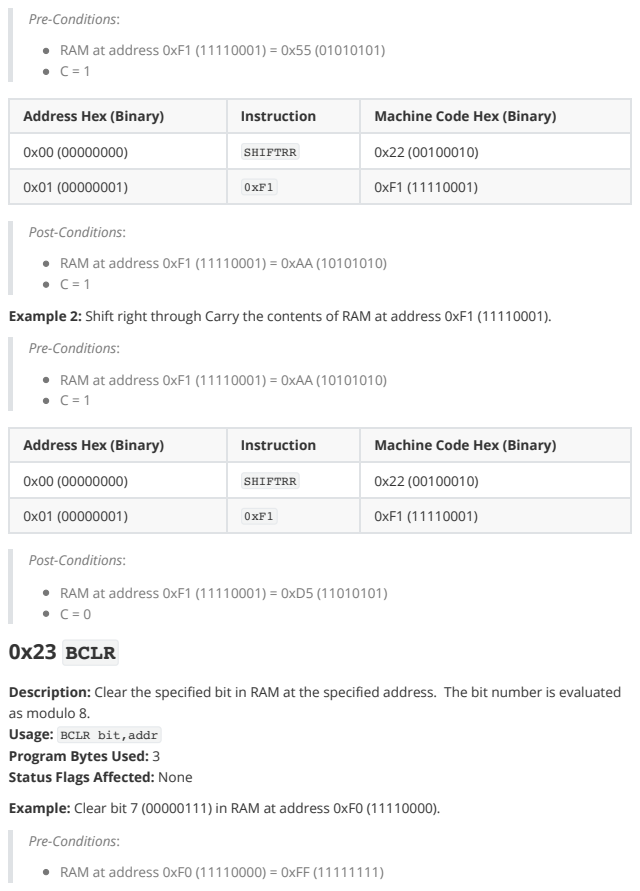
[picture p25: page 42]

Pre-Conditions:
RAM at address 0xF1 (11110001) = 0x55 (01010101)

Address Hex (Binary) | Instruction | Machine Code Hex (Binary)

0x00 (00000000) | SHIFTRR | 0x22 (00100010)

Post-Conditions:
RAM at address 0xF1 (11110001) = 0xAA (10101010)
Example 2: Shift right through Carry the contents of RAM at address 0xF1 (11110001).

RAM at address 0xF1 (11110001) = 0xD5 (11010101)
0x23 BCLR

Description: Clear the specified bit in RAM at the specified address. The bit number is evaluated
as modulo 8.
Usage: BCLR bit,addr
Program Bytes Used: 3
Status Flags Affected: None
Example: Clear bit 7 (00000111) in RAM at address 0xF0 (11110000).
RAM at address 0xF0 (11110000) = 0xFF (11111111)

Address Hex (Binary) | Instruction | Machine Code Hex (Binary)

0x00 (00000000) | BCLR | 0x23 (00100011)

Post-Conditions:
RAM at address 0xF0 (11110000) = 0x7F (01111111)
0x24 BSET

Description: Set the specified bit in RAM at the specified address. The bit number is evaluated as
modulo 8.
Usage: BSET bit,addr
Program Bytes Used: 3
Status Flags Affected: None
Example: Set bit 7 (00000111) in RAM at address 0xF0 (11110000).
Pre-Conditions:
RAM at address 0xF0 (11110000) = 0x00 (00000000)

0x00 (00000000) | BSET | 0x24 (00100100)

RAM at address 0xF0 (11110000) = 0x80 (10000000)
0x25 BCHG

Description: Change (invert) the specified bit in RAM at the specified address. The bit number is
evaluated as modulo 8.
Usage: BCHG bit,addr
Example: Change bit 3 (00000011) in RAM at address 0xF0 (11110000).
RAM at address 0xF0 (11110000) = 0xA5 (10100101)

Address Hex (Binary) | Instruction | Machine Code Hex (Binary)
0x00 (00000000) | BTSTSC | 0x26 (00100110)
0x01 (00000001) | 0x02 | 0x02 (00000010)
0x02 (00000010) | 0xF9 | 0xF9 (11111001)
0x03 (00000011) | JUMP | 0x28 (00101000)
0x04 (00000100) | 0x10 | 0x10 (00010000)
0x05 (00000101) | HALT | 0x00 (00000000)

RAM at address 0xF0 (11110000) = 0xAD (10101101)

### 0x26 BTSTSC

Description: Test the specified bit in RAM at the specified address. If it is clear (0), advance the Program Counter by two. The bit number is evaluated as modulo 8.
Usage: BTSTSC bit,addr
Program Bytes Used: 3
Status Flags Affected: None

Example 1: Test bit 2 (00000010) in RAM at address 0xF9 (11111001). Since it is clear (0), execution continues with the HALT instruction.

Pre-Conditions:

RAM at address 0xF9 (11111001) = 0x03 (00000011)

Post-Conditions:

RAM at address 0xF9 (11111001) = 0x03 (00000011)

Example 2: Test bit 2 (00000010) in RAM at address 0xF9 (11111001). Since it is set (1), execution continues with the JUMP instruction.

Pre-Conditions:

RAM at address 0xF9 (11111001) = 0x0F (00001111)

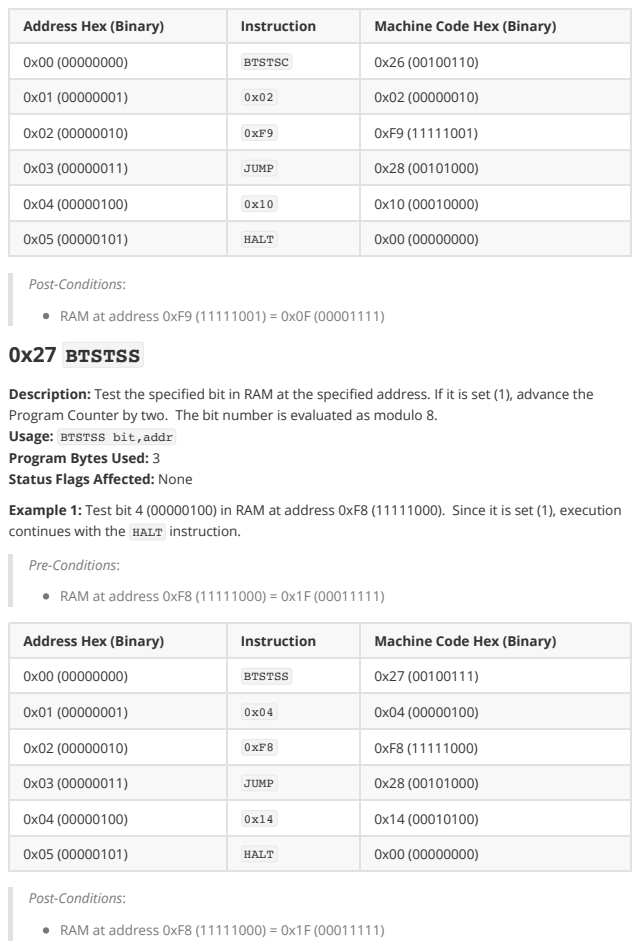
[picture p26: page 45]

Address Hex (Binary) | Instruction | Machine Code Hex (Binary)

0x00 (00000000) | BTSTSC | 0x26 (00100110)

0x03 (00000011) | JUMP | 0x28 (00101000)

0x05 (00000101) | HALT | 0x00 (00000000)

Post-Conditions:
RAM at address 0xF9 (11111001) = 0x0F (00001111)
0x27 BTSTSS

Description: Test the specified bit in RAM at the specified address. If it is set (1), advance the
Program Counter by two. The bit number is evaluated as modulo 8.
Usage: BTSTSS bit,addr
Program Bytes Used: 3
Status Flags Affected: None
Example 1: Test bit 4 (00000100) in RAM at address 0xF8 (11111000). Since it is set (1), execution
continues with the HALT instruction.
Pre-Conditions:
RAM at address 0xF8 (11111000) = 0x1F (00011111)

0x00 (00000000) | BTSTSS | 0x27 (00100111)

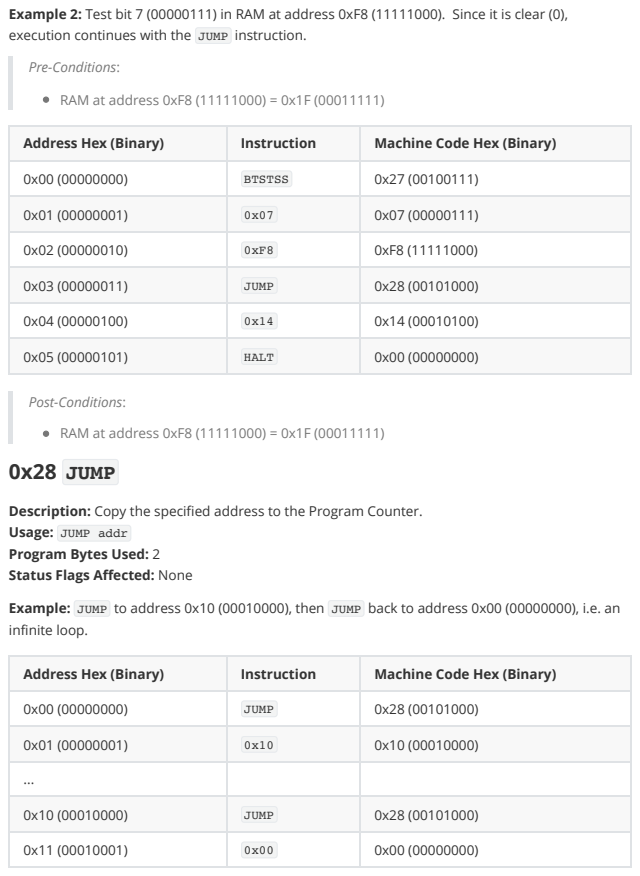
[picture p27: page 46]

Example 2: Test bit 7 (00000111) in RAM at address 0xF8 (11111000). Since it is clear (0),
execution continues with the JUMP instruction.
Pre-Conditions:
RAM at address 0xF8 (11111000) = 0x1F (00011111)

Address Hex (Binary) | Instruction | Machine Code Hex (Binary)

0x00 (00000000) | BTSTSS | 0x27 (00100111)

0x03 (00000011) | JUMP | 0x28 (00101000)

0x05 (00000101) | HALT | 0x00 (00000000)

Post-Conditions:
0x28 JUMP

Description: Copy the specified address to the Program Counter.
Usage: JUMP addr
Program Bytes Used: 2
Status Flags Affected: None
Example: JUMP to address 0x10 (00010000), then JUMP back to address 0x00 (00000000), i.e. an
infinite loop.

0x00 (00000000) | JUMP | 0x28 (00101000)

0x10 (00010000) | JUMP | 0x28 (00101000)

Address Hex (Binary) | Instruction | Machine Code Hex (Binary)
0x00 (00000000) | JUMPI | 0x29 (00101001)
0x01 (00000001) | 0x10 | 0x10 (00010000)

0x10 (00010000) | 0x20 | 0x20 (00100000)

0x20 (00100000) | NOP | 0x01 (00000001)

### 0x29 JUMPI

Description: Copy the contents of RAM at the specified address to the Program Counter.
Usage: JUMPI addr
Program Bytes Used: 2
Status Flags Affected: None

Example: JUMPI to the address contained in RAM at address 0x10 (00010000). Execution continues with the NOP instruction.

## 0x2A CALL

Description: Push the Program Counter to the stack, then copy the specified address to the Program Counter.
Usage: CALL addr
Program Bytes Used: 2
Status Flags Affected: None

Example: Call the subroutine at address 0x10 (00010000), copy the contents of the Button Register to the Data LEDs Register, then return and stop.

Address Hex (Binary) | Instruction | Machine Code Hex (Binary) | Remarks
0x00 (00000000) | CALL | 0x2A (00101010)
0x01 (00000001) | 0x10 | 0x10 (00010000)
0x02 (00000010) | HALT | 0x00 (00000000)

0x10 (00010000) | COPYRR | 0x0A (00001010)
0x11 (00010001) | 0xFD | 0xFD (11111101) | Button Register
0x12 (00010010) | 0xFF | 0xFF (11111111) | Data LEDs Register
0x13 (00010011) | RETURN | 0x2C (00101100)
Address Hex (Binary) | Instruction | Machine Code Hex (Binary)
0x00 (00000000) | CALLI | 0x2B (00101011)
0x01 (00000001) | 0x10 | 0x10 (00010000)

0x10 (00010000) | 0x20 | 0x20 (00100000)

0x20 (00100000) | NOP | 0x01 (00000001)

Tip: Use this instruction to execute a subroutine. When the subroutine executes a RETURN (or RETLA ) instruction, execution continues with the instruction immediately following the CALL instruction.

### 0x2B CALLI

Description: Push the Program Counter to the stack, then copy the contents of RAM at the specified address to the Program Counter.
Usage: CALLI addr
Program Bytes Used: 2
Status Flags Affected: None

Example: Call the subroutine at the address contained in RAM at address 0x10 (00010000). Execution continues with the NOP instruction.

Address Hex (Binary) | Instruction | Machine Code Hex (Binary) | Remarks
0x00 (00000000) | CALL | 0x2A (00101010)
0x01 (00000001) | 0x10 | 0x10 (00010000)
... | | | Return value used here
0x10 (00010000) | RETLA | 0x2D (00101101) | Subroutine
0x11 (00010001) | 0x01 | 0x01 (00000001) | Return value

Tip: Use this instruction to execute a subroutine. When the subroutine executes a RETURN (or RETLA ) instruction, execution continues with the instruction immediately following the CALLI instruction.

### 0x2C RETURN

Description: Pop the stack to the Program Counter. Usage: RETURN
Program Bytes Used: 1
Status Flags Affected: None

Example: Refer to the CALL instruction example.

Tip: Use this instruction to return from a subroutine. Execution continues with the instruction immediately following the most recent CALL (or CALLI ) instruction.

### 0x2D RETLA

Description: Copy the literal value to the Accumulator, then pop the stack to the Program Counter.
Usage: RETLA lit
Program Bytes Used: 2
Status Flags Affected: None

Example: Call the subroutine at address 0x10 (00010000). The subroutine returns with a value of 0x01 (00000001) in the Accumulator.

Tip: Use this instruction to return from a subroutine and pass a return value to the caller. Execution continues with the instruction immediately following the most recent CALL (or CALLI ) instruction.

Address Hex (Binary) | Instruction | Machine Code Hex (Binary) | RAM Value Added
0x10 (00010000) | ADDRPC | 0x2E (00101110)
0x11 (00010001) | 0xF0 | 0xF0 (11110000)
0x12 (00010010) | JUMP | 0x28 (00101000) | 0x00
0x13 (00010011) | 0x80 | 0x80 (10000000)
0x14 (00010100) | JUMP | 0x28 (00101000) | 0x02
0x15 (00010101) | 0xA0 | 0xA0 (10100000)
0x16 (00010110) | JUMP | 0x28 (00101000) | 0x04
0x17 (00010111) | 0xC0 | 0xC0 (11000000)

### 0x2E ADDRPC

Description: Add the contents of RAM at the specified address to the Program Counter.
Usage: ADDRPC addr
Program Bytes Used: 2
Status Flags Affected: None

Example: Transfer control to one of three addresses depending on the contents of RAM at address 0xF0 (11110000). In this case, RAM contains 0x04 (00000100), so execution continues at address 0xC0 (11000000).

Pre-Conditions:

RAM at address 0xF0 (11110000) = 0x04 (00000100)

Post-Conditions:

RAM at address 0xF0 (11110000) = 0x04 (00000100)

### 0x2F RANDA

Description: Store a pseudo-random number (0x00..0xFF) in the Accumulator. Usage: RANDA
Program Bytes Used: 1
Status Flags Affected: None

Example: Display a random number on the Data LEDs.

Description: Output the character in the Accumulator from the Comm Port. Usage: COMOUT
Program Bytes Used: 1

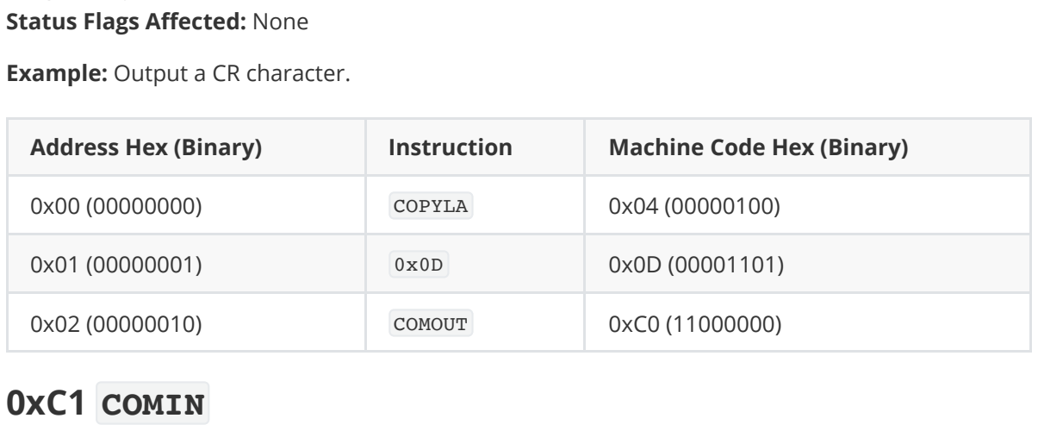
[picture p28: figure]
Address Hex (Binary); Instruction; Machine Code Hex (Binary); COPYLA; COMOUT; Status Flags Affected: None; Example: Output a CR character.; 0xC1 COMIN

Description: Input a character from the Comm Port to the Accumulator. If no character is available, block (prevent continued execution of) the program indefinitely until at least one character has been received.
Usage: COMIN
Program Bytes Used: 1
Status Flags Affected: None

Example: Input a character and display its value on the Data LEDs.

Address Hex (Binary) | Instruction | Machine Code Hex (Binary) | Remarks
0x00 (00000000) | SPEED | 0x02 (00000010)
0x01 (00000001) | 0x06 | 0x06 (00000110) | 200 instructions per second
0x02 (00000010) | COMRDY | 0xC2 (11000010)
0x03 (00000011) | BTSTSS | 0x27 (00100111)
0x04 (00000100) | 0x00 | 0x00 (00000000) | Z flag
0x05 (00000101) | 0xFC | 0xFC (11111100) | Status Register
0x06 (00000110) | COMIN | 0xC1 (11000001)
0x07 (00000111) | COMOUT | 0xC0 (11000000)
0x08 (00001000) | INCR | 0x1E (00011110)
0x09 (00001001) | 0xFF | 0xFF (11111111) | Data LEDs Register
0x0A (00001010) | JUMP | 0x28 (00101000)
0x0B (00001011) | 0x02 | 0x02 (00000010)

Tip: If you don't want your program to block while waiting for a character to be received, use the COMRDY instruction to check for character availability before executing COMIN .

Note: Characters received at the Comm Port are internally buffered by the firmware. COMIN delivers them to your program on a "first in, first out" basis.

### 0xC2 COMRDY

Description: Test for availability of received characters from the Comm Port. The Z flag is set if there are zero characters available (i.e. COMIN would block if executed), or cleared if there is at least one character available.
Usage: COMRDY
Program Bytes Used: 1
Status Flags Affected: Z

Example: If a character is received from the terminal, echo it to the terminal, while simultaneously incrementing the Data LEDs.

Pinmask | Accumulator / Pins
0x01 (00000001) | xxxxxxxA
0x02 (00000010) | xxxxxxxB
0x03 (00000011) | xxxxxxBA
Address Hex (Binary) | Instruction | Machine Code Hex (Binary) | Remarks
0x04 (00000100) | COPYLA | 0x04 (00000100)
0x05 (00000101) | 0x00 | 0x00 (00000000) | Low
0x06 (00000110) | PINOUT | 0xC4 (11000100)
0x07 (00000111) | 0x01 | 0x01 (00000001) | A pin
Address Hex (Binary) | Instruction | Machine Code Hex (Binary) | Remarks
0x04 (00000100) | COPYLA | 0x04 (00000100)
0x05 (00000101) | 0x01 | 0x01 (00000001) | High
0x06 (00000110) | PINOUT | 0xC4 (11000100)
0x07 (00000111) | 0x02 | 0x02 (00000010) | B pin

### 0xC4 PINOUT

Description: Output the contents of the Accumulator to the Expansion Port A and/or B pin.
Usage: PINOUT pinmask
Program Bytes Used: 2
Status Flags Affected: None

Example 1: Output low on the Expansion Port A pin.

Pre-Conditions:

The pins have already been configured as outputs, as shown in the PINDIR example.

Example 2: Output high on the Expansion Port B pin.

Pre-Conditions:

The pins have already been configured as outputs, as shown in the PINDIR example.

Example 3: Output the D0 and D1 button states to the Expansion Port A and B pins, respectively.

Pre-Conditions:

The pins have already been configured as outputs, as shown in the PINDIR example.

Address Hex (Binary) | Instruction | Machine Code Hex (Binary) | Remarks
0x04 (00000100) | COPYRA | 0x09 (00001001)
0x05 (00000101) | 0xFD | 0xFD (11111101) | Button Register
0x06 (00000110) | PINOUT | 0xC4 (11000100)
0x07 (00000111) | 0x03 | 0x03 (00000011) | A and B pins
0x08 (00001000) | JUMP | 0x28 (00101000)
0x09 (00001001) | 0x04 | 0x04 (00000100)
Pinmask | Accumulator / Pins
0x01 (00000001) | 0000000A
0x02 (00000010) | 0000000B
0x03 (00000011) | 000000BA

### 0xC5 PININ

Description: Input from the Expansion Port A and/or B pin to the Accumulator. Bits of the Accumulator not updated from a pin are cleared.
Usage: PININ pinmask
Program Bytes Used: 2
Status Flags Affected: Z

Example 1: Input from the Expansion Port A pin.

The pins have already been configured as inputs, as shown in the PINDIR example.

Accumulator = 0x00 (00000000) if A pin is low, or 0x01 (00000001) if A pin is high. Z = 1 if A pin is low, or 0 if A pin is high

Example 2: Input from the Expansion Port B pin.

Pre-Conditions:

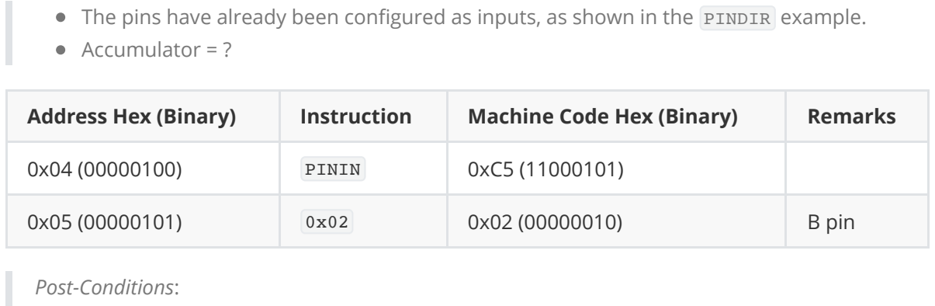
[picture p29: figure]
Address Hex (Binary); Instruction; Machine Code Hex (Binary); Remarks; PININ; B pin; Accumulator = ?; Post-Conditions:

Address Hex (Binary) | Instruction | Machine Code Hex (Binary) | Remarks
0x04 (00000100) | PININ | 0xC5 (11000101)
0x05 (00000101) | 0x03 | 0x03 (00000011) | A and B pins
0x06 (00000110) | COPYAR | 0x07 (00000111)
0x07 (00000111) | 0xFF | 0xFF (11111111) | Data LEDs Register
0x08 (00001000) | JUMP | 0x28 (00101000)
0x09 (00001001) | 0x04 | 0x04 (00000100)

The pins have already been configured as inputs, as shown in the PINDIR example.

Accumulator = 0x00 (00000000) if B pin is low, or 0x01 (00000001) if B pin is high.
Z = 1 if B pin is low, or 0 if B pin is high

Example 3: Input from the Expansion Port A and B pins and display the value on the Data LEDs.

Pre-Conditions:

The pins have already been configured as inputs, as shown in the PINDIR example.

### 0xC6 PINDIR

Description: Configure the direction of the Expansion Port A and/or B pin. If the corresponding Accumulator bit is 0/1 the pin is made an Output/Input, respectively.

Usage: PINDIR pinmask
Program Bytes Used: 2
Status Flags Affected: None

Pinmask | Accumulator / Pins
0x01 (00000001) | xxxxxxxA
0x02 (00000010) | xxxxxxxB
0x03 (00000011) | xxxxxxBA
Address Hex (Binary) | Instruction | Machine Code Hex (Binary) | Remarks
0x00 (00000000) | COPYLA | 0x04 (00000100)
0x01 (00000001) | 0x00 | 0x00 (00000000) | Output
0x02 (00000010) | PINDIR | 0xC6 (11000110)
0x03 (00000011) | 0x01 | 0x01 (00000001) | A pin
Address Hex (Binary) | Instruction | Machine Code Hex (Binary) | Remarks
0x00 (00000000) | COPYLA | 0x04 (00000100)
0x01 (00000001) | 0x01 | 0x01 (00000001) | Input
0x02 (00000010) | PINDIR | 0xC6 (11000110)
0x03 (00000011) | 0x02 | 0x02 (00000010) | B pin
Address Hex (Binary) | Instruction | Machine Code Hex (Binary) | Remarks
0x00 (00000000) | COPYLA | 0x04 (00000100)
0x01 (00000001) | 0x00 | 0x00 (00000000) | Outputs
0x02 (00000010) | PINDIR | 0xC6 (11000110)
0x03 (00000011) | 0x03 | 0x03 (00000011) | A and B pins

Caution: Any pin configured for input must not be allowed to "float" at an indeterminate voltage level. Use an external pull-up/down resistor if necessary.

Caution: Whenever the CPU is reset, the Expansion Port pins are reconfigured as low-driven outputs. Be mindful of possible contention with external hardware.

Example 1: Configure the Expansion Port A pin as output.

Example 2: Configure the Expansion Port B pin as input.

Example 3: Configure the Expansion Port A and B pins as outputs.

Example 4: Configure the Expansion Port A and B pins as inputs.

Address Hex (Binary) | Instruction | Machine Code Hex (Binary) | Remarks
0x00 (00000000) | COPYLA | 0x04 (00000100)
0x01 (00000001) | 0x03 | 0x03 (00000011) | Inputs
0x02 (00000010) | PINDIR | 0xC6 (11000110)
0x03 (00000011) | 0x03 | 0x03 (00000011) | A and B pins

# Using the Debug Monitor

The Digirule 2U has a built-in debug monitor that provides the following functions:

Display memory
Disassemble memory
Edit memory
Fill memory
Load memory (from a non-volatile memory file) Save memory (to a non-volatile memory file) Display registers
Edit Accumulator
Edit breakpoint
Edit Program Counter
Run/stop program
Single-step program
Reset CPU

To start the monitor, with the Digirule 2U in Stop mode, press and hold the Load button, then press the Store button. The Digirule 2U enters Monitor mode. The usual memory editing and CPU control button functions are disabled.

This mode can be cancelled by pressing the Run/Stop button or selecting Quit at the monitor prompt, and the Digirule 2U enters Stop mode.

Tip: Because the monitor itself requires use of the Comm Port to interact with the user on the terminal, its use is not recommended for debugging programs that perform terminal input using the COMIN instruction.

Note: The Comm Port configuration is 9600 baud, 8 data bits, no parity, 1 stop bit.

## Monitor Functions

The menu shows the list of functions provided by the monitor, and the associated shortcut keys to initiate them. The build date of the firmware is also shown here.

### Display Memory

This function displays the entire memory address space in both hexadecimal and ASCII formats. Once started, you can stop the display prematurely by pressing any key. An asterisk * appears to the left of the memory location currently pointed to by the Program Counter.

I - Disassemble Memory
E - Edit Memory
F - Fill Memory
L - Load Memory
V - Save Memory

R - Display Registers
A - Edit Accumulator
B - Edit Breakpoint
P - Edit Program Counter

G - Go (Run)
S - Step
Z - Reset CPU

? - Display Menu
Q - Quit

>

> Display Memory
00 *02 01 05 20 06 09 00 26 00 FC 28 02 C0 1E 06 28 | |... ...&..(....(|
10 | 05 00 00 00 00 00 00 00 00 00 00 00 00 00 00 00 | | | |
20 | 0D 0A 20 5F 20 20 5F 20 20 20 20 20 5F 20 5F 20 | |.. _ _ | _ _ |
30 | 20 20 20 20 20 5F 5F 20 20 20 20 20 20 5F 5F 20 | | | __ | | __ |
40 | 20 20 20 20 20 20 5F 20 20 20 20 5F 20 20 20 5F | | | _ | _ | _|
50 | 20 0D 0A 7C 20 7C 7C 20 7C 5F 5F 5F 7C 20 7C 20 | | ..| || |___| | |
60 | 7C 5F 5F 5F 20 20 5C 20 5C 20 20 20 20 2F 20 2F | ||___ \ \ | / /|
70 | 5F 5F 20 5F 20 5F 7C 20 7C 5F 5F 7C 20 7C 20 7C | |__ _ _| |__| | ||
80 | 20 7C 0D 0A 7C 20 5F 5F 20 2F 20 2D 5F 29 20 7C | | |..| __ / -_) ||
90 | 20 2F 20 5F 20 5C 20 20 5C 20 5C 2F 5C 2F 20 2F | | / _ \ | \ \/\/ /|
A0 | 20 5F 20 5C 20 27 5F 7C 20 2F 20 5F 60 20 7C 20 | | _ \ '_| / _` | |
B0 | 7C 5F 7C 0D 0A 7C 5F 7C 7C 5F 5C 5F 5F 5F 7C 5F | ||_|..|_||_\___|_|
C0 | 7C 5F 5C 5F 5F 5F 2F 20 20 20 5C 5F 2F 5C 5F 2F | ||_\___/ | \_/\_/|
D0 | 5C 5F 5F 5F 2F 5F 7C 20 7C 5F 5C 5F 5F 2C 5F 7C | |\___/_| |_\__,_||
E0 | 20 28 5F 29 0D 0A 00 00 00 00 00 00 00 00 00 00 | | (_) | |
F0 | 00 00 00 00 00 00 00 00 00 00 00 00 00 00 00 00 | | | |

### Disassemble Memory

This function disassembles memory starting at the specified address (default is the address in the Program Counter).

### Edit Memory

This function allows you to inspect and/or modify memory starting at the specified address. To change the data contained in the memory location, type in the new data value. The address will automatically advance to the next location. To advance to the next location without changing the current data, press the space key. When you are finished editing, press the return key.

### Fill Memory

This function fills memory from the specified start address to (and including) the specified end address with the specified data value.

> Disassemble Memory | Address (default=PC) ?
00 SPEED | 01
02 COPYLR | 20 06
05 COPYRA 00
07 BTSTSC | 00 FC
0A JUMP | 02
0C COMOUT
0D INCR | 06
0F JUMP | 05
11 HALT
12 HALT
13 HALT
14 HALT
> Edit Memory | Address? 00
00=02 ?
01=01 ? 08
02=05 ?
03=20 ?
04=06 ? 07
05=09 ?
06=00 ?
> Fill Memory | Start address? 00 | End address? FF | Data? 55

### Load Memory

This function loads memory from the specified non-volatile memory file.

### Save Memory

This function saves the current contents of memory to the specified non-volatile memory file.

### Display Registers

This function displays the contents of the following registers

Program Counter
Status Register (including the individual bits within)
Accumulator
Stack Pointer (0 means the stack is empty)

and disassembles the instruction at the memory location pointed to by the Program Counter, i.e. the next instruction to be executed.

### Edit Accumulator

This function allows you to inspect and/or modify the contents of the Accumulator.

### Edit Breakpoint

This function allows you to inspect and/or modify the breakpoint address. When the monitor is running a program and the Program Counter reaches this address, the program is stopped and

the current register contents are displayed. To disable the breakpoint, set it to FF .

### Edit Program Counter

This function allows you to inspect and/or modify the address in the Program Counter.

> Load Memory | Location (0-7) ? 0
> Save Memory | Location (0-7) ? 0
PC=00 | SR=00 ... | AC=00 | SP=00 | @PC=SPEED 01
> Edit Accumulator | AC=00 | Data? FF
> Edit Breakpoint | BP=FF | Address (FF=disable) ? 10
> Edit Program Counter | PC=00 | Address? 20

### Go (Run)

This function starts the CPU. Execution begins at the address in the Program Counter. Press any key to stop the CPU. The register contents at the stopping point are automatically displayed. To resume execution, issue Go again.

### Step

This function single-steps the CPU (i.e. executes a single instruction, then stops). The register

### Reset CPU

This function resets the CPU, including the following items:

Address LED blanking is disabled
The Stack Pointer is reset to the top of the stack
The Program Counter is reset to 0
The Status Register is reset to 0
The Accumulator is reset to 0
The instruction execution interval (speed) is reset to 0 (maximum speed) The Expansion Port pins are returned to their default state (low outputs)

This is the most reliable way to restart a program.

### Display Menu

This function redisplays the monitor menu.

> Go
_ _ | _ _ | __ | __ | _ | _ | _
| || |___| | |___ \ \ | / /__ _ _| |__| | | |
| __ / -_) | / _ \ | \ \/\/ / _ \ '_| / _` | |_|
|_||_\___|_|_\___/ | \_/\_/\___/_| |_\__,_| (_)

Stop
PC=05 | SR=00 ... | AC=20 | SP=00 | @PC=COPYRA 3C
PC=07 | SR=00 ... | AC=20 | SP=00 | @PC=BTSTSC | 00 FC
PC=00 | SR=00 ... | AC=00 | SP=00 | @PC=SPEED | 01

### Quit

This function exits the monitor, and the Digirule 2U enters Stop mode.

# Using the Expansion Port

The Digirule 2U Expansion Port is a 10-pin connector pad located in the lower-right corner of the board. It features three distinct electrical interfaces:

UART
Pin I/O
ICSP

## UART Interface

The UART interface (Rx and Tx pins, and GND) provides standard full-duplex serial data communication with similar external devices, and is compatible with 3-volt logic levels^1^. The receive (Rx) input has a built-in pull-up resistor to keep it in the Mark (idle) state when not driven externally.

This interface works in tandem with the USB interface. Data sent from the microcontroller is simultaneously transmitted on both interfaces. Data received on either interface is combined and sent to the microcontroller as a single data stream. All Comm Port-based functions that work on the USB interface (including COMOUT , COMIN and COMRDY instructions, loading or saving RAM in hex format, using the Debug Monitor, and installing firmware updates) will work equally well on the UART interface.

Caution: Simultaneous reception on both USB and UART interfaces is not supported and will result in data corruption.

Tip: Two Digirule 2Us may communicate with each other using a simple three-wire connection between their UART interfaces. Connect Rx1 to Tx2, Tx1 to Rx2, and GND1 to GND2.

Note: The Comm Port configuration is 9600 baud, 8 data bits, no parity, 1 stop bit.

## Pin I/O Interface

The Pin I/O interface (A and B pins, and GND) provides bi-directional digital communication with external hardware, such as LEDs or switches, and is compatible with 3-volt logic levels^1^. This interface works in conjunction with the PINOUT , PININ and PINDIR instructions. Each pin can be individually (or both pins can be simultaneously) configured to be input or output, high or low. Both pins are configured as low-driven outputs whenever the Digirule 2U CPU is reset. A pin configured for output can also be read with the PININ instruction. Similarly, a pin configured for input can also be written with the PINOUT instruction, but the latched level will not be driven onto the pin until reconfigured for output. This makes it possible to implement an open-collector /

> Quit open-drain / wired-OR circuit.

Caution: The pins are connected directly to the microcontroller and are not buffered in any way. Use the same circuitry precautions as you would with any other microcontroller. There are no pull-up resistors on either pin. If you configure either pin for input, ensure that proper logic voltage levels are maintained at all times, and provide external pull-up resistors if necessary. If you configure either pin for output, ensure that external circuitry is not also attempting to drive the pin at the same time, and use proper current-limiting resistors if necessary. The Expansion Port Vcc pin may be used to supply a limited amount of power to external circuitry. In any case, do not source more than a combined total of 25 mA from the Vcc, A and B pins or you risk damaging the Digirule 2U circuitry. That's roughly the current consumption of just a single LED.

## ICSP Interface

The ICSP (In-Circuit Serial Programming) interface is compatible with Microchip PIC programming tools. If you intend to develop your own firmware for the Digirule 2U and have the necessary equipment, this is the connection point for your development system.

^1^Caution: When the battery is the power source, the Digirule 2U Vcc voltage will decline over time as the battery drains. External circuitry must be designed to accommodate this. Typically this involves using the Digirule 2U Vcc pin as the voltage reference for external pull-up resistors or logic-level translators. If the difference between Vcc and external signal drive levels becomes extreme, it can lead to communication problems, or even damage to the Digirule 2U circuitry.

# Updating the Firmware

The Digirule 2U has a built-in firmware updater capable of installing new versions of firmware without the need for special programming hardware. Firmware updates, when available, can be downloaded from the Digirule 2U website, and will be supplied as a hex file.

Updating the firmware requires use of a software utility called udr2. This utility is available for download from the Digirule 2U website for Linux, Mac and Windows operating systems. The udr2 utility works with the Digirule 2U to install the contents of the hex file into the proper memory locations within the microcontroller.

Caution: Any programs you have saved to non-volatile memory files will be replaced with the original sample programs during the firmware update process. Be sure to transfer any files you want to keep to your computer for safekeeping prior to performing the update. You can then restore them after the update.

To update the Digirule 2U firmware, perform the following steps:

1. Power off the Digirule 2U by turning off the power switch and disconnecting from USB.
2. Hold down the Goto and Load buttons.
3. Power on the Digirule 2U by turning on the power switch or connecting to USB. The Run and Stop LEDs will alternately blink.
4. Release the buttons.

5. If not already connected to USB from Step 3, do so now.
6. Run the udr2 utility on your computer:
./udr2 < dr2u.firmware.vXX.hex /dev/ttyUSB0 ^2^
The process takes approximately one minute. When finished, the Digirule 2U automatically restarts, and you will see the familiar startup animation on the LEDs.
7. The Digirule 2U is now ready for use. Disconnect from USB if desired.

^2^This example command line is for Linux. Substitute a command line appropriate for your operating system. Please refer to the UDR2 Digirule 2U Firmware Updater User Manual for more information.

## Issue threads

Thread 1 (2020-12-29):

1+1=3?

richmans, 2020-12-29:
This thing is really fun to play with! (which is definitely not the issue)

I wanted to implement a dice-simulation program. It generates a random number 0-255 which i then try to reduce to a number 1-6.

So i have the following program:
```
  00 SPEED   40
  02 RANDA
  03 COPYAR  E0
  05 COPYLR  2A E1
  08 DIV     E0 E1
  0B COPYRA  E0
  0D SUBLA   06
  0F BTSTSC  00 FC
  12 JUMP    00
  14 COPYRA  E0
  16 ADDLA   01
  18 COPYAR  FF
  1A BTSTSC  07 FD
  1D JUMP    00
  1F JUMP    1A
```

Now if i run this, the `ADDLA 1` at 16 seems to somehow add 2 to the A register instead of 1. So i put a breakpoint on 16, and then stepped through it:

```
> Edit Breakpoint | BP=16 | Address (FF=disable) ? 16
> Go Break
PC=16 | SR=02 .C. | AC=04 | SP=00 | @PC=ADDLA   01
> Display Registers
PC=16 | SR=02 .C. | AC=04 | SP=00 | @PC=ADDLA   01
> Step
PC=18 | SR=00 ... | AC=06 | SP=00 | @PC=COPYAR  FF
>
```

I've done multiple tests, no matter what the AC contains, it always adds 2.

I'm thinking the ADDLA is not functioning in this case?  I tested `COPYLA 1, ADDLA 1`, that works properly. Is there some flag that influences this? Or the RANDA instruction?

Curious to hear what you think!

Richard

photonverse, 2020-12-29:
Hi Richard,

I see that Carry bit was set:

> Display Registers
PC=16 | SR=02 .C. | AC=04 | SP=00 | @PC=ADDLA   01

Try "BSET 1 FC" to clear the carry bit before ADDLA instruction.

Kwang

On Tue, Dec 29, 2020 at 11:19 AM Richard Bronkhorst <
notifications@github.com> wrote:

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

bradsprojects, 2020-12-29:
Hi Richard,

This is normal behaviour for the DR2U. When stepping through your program you can see the the carry flag is set within the Status Register (SR=02) prior to the ADDLA instruction being executed.

If you have a look in the Digirule 2U User Manual, you will find the ADDLA instruction will add a literal value to the accumulator and the carry flag also.

To get your program to work correctly, you simply need to clear the carry flag prior to the ANDLA instruction like this:

`00 SPEED   40
  02 RANDA
  03 COPYAR  E0
  05 COPYLR  2A E1
  08 DIV     E0 E1
  0B COPYRA  E0
  0D SUBLA   06
  0F BTSTSC  00 FC
  12 JUMP    00
  14 COPYRA  E0
  16 BCLR 01 FC
  19 ADDLA   01
  1B COPYAR  FF
  1D BTSTSC  07 FD
  20 JUMP    00
  22 JUMP    1A`

photonverse, 2020-12-29:
Oops. I meant to say "BCLR 1 FC" (clear carrybit for STATUS REGISTER).

bradsprojects, 2020-12-29:
Oh, I see you beat me to it @photonverse :)

richmans, 2020-12-29:
I see! Thanks! I wrote quite a bit of x86 assembly and never saw this behavior in an add instruction so i didn't expect it. Wouldn't it be more intuitive to ignore the carry flag? The incr instruction doesn't use it.

Anyway, should be able to get this working now, thanks! And thanks for building this great toy! :-)

kd0gls, 2020-12-29:
Including the carry bit in the ADDxx/SUBxx instructions supports the addition/subtraction of multi-byte numbers.  The 24-bit counter sample program provides an example of this.

Closed 2020-12-30.

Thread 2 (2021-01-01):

Please specify serial port flow control in the manual

rlcarr, 2021-01-01:
Could you update the User Manual to specify which flow control scheme should be used when connecting a serial terminal?  Should it be XON/XOFF?  CTS/RTS?  None? Something else?

kd0gls, 2021-01-01:
Hi rlcarr,

The flow control setting which is often present in communications software is just one of many possible serial device settings you may need to configure, and we don't presume how they should all be set.  We provide only the most essential settings in the user manual.  The Digirule 2U does not support any form of flow control, and you will likely have no trouble communicating with the device regardless of which flow control option you choose, however I would recommend "none".

Closed 2021-01-01.

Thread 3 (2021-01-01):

Please specify in the User Manual how to download programs from Linux and Mac

rlcarr, 2021-01-01:
There is a Mac program download utility but none for Windows and Linux.

Please say in the User Manual how to download programs from a Windows or Linux computer into the Digirule (even if it's just "cat the .hex file to the serial port".  If programs cannot be downloaded from Windows or Mac until a download utility is released in the future, please say that.

kd0gls, 2021-01-01:
Hi rlcarr,

The "dldr2" utility is not provided for Linux or Windows simply because its sole purpose is to work around a problem that is unique to the Mac command line.  On Linux and Windows the standard command-line redirection mechanism works as expected without the need for assistance from an external utility.  And if you use a terminal emulator program to perform your transfers, there's no need for the utility at all, even on Mac.

We have declined at this time to document any one particular command or mechanism for transferring data between the operating system and the serial device to which the Digirule 2U is attached, simply because the ways in which this can be accomplished are many and better documented elsewhere.

Closed 2021-01-01.

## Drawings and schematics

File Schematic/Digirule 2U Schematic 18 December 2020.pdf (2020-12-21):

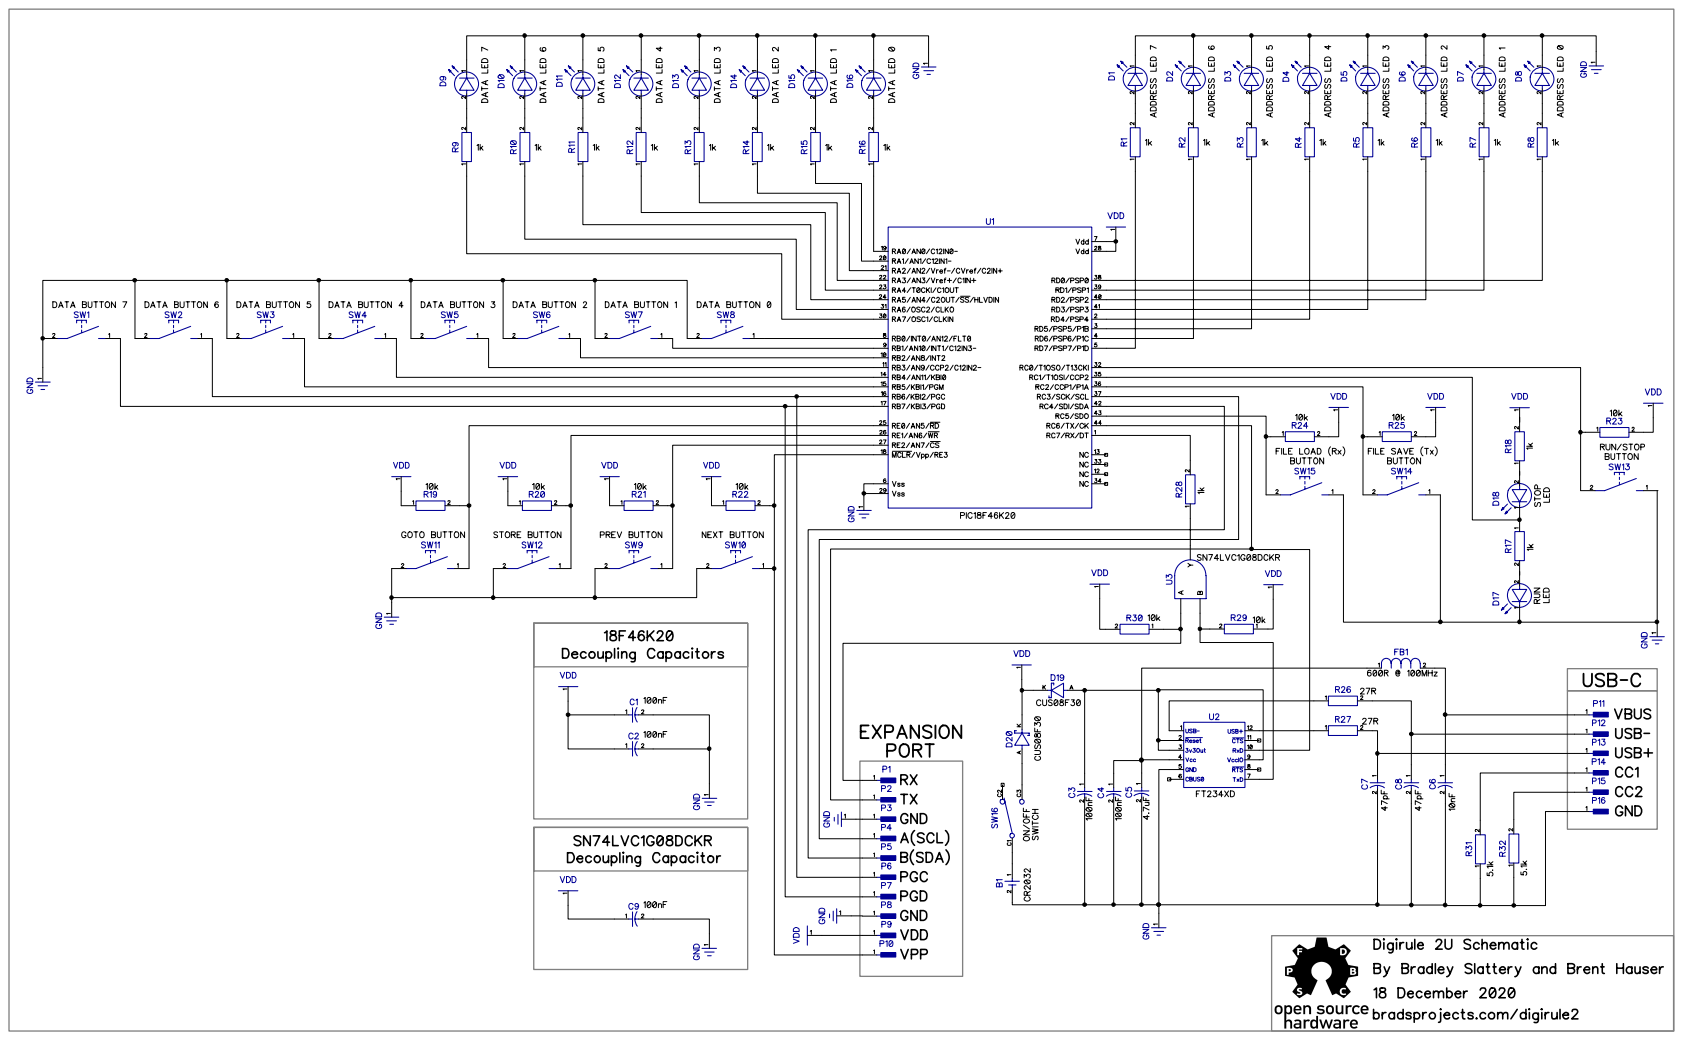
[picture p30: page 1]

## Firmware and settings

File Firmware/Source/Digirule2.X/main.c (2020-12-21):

#include "digirule2.h"

bool_t t1ms;

void (*process_fn)( void ) = cpu_process;

void main( void )
{
	OSCCONbits.IRCF = 0b111;	// Fosc to 16 MHz
	
	// initialize ports
	ANSEL	= 0b00000000;		// all analog-capable pins to digital
	ANSELH	= 0b00000000;
	
	LATA	= 0b00000000;
	TRISA	= 0b00000000;		// RA7..0 (DATA LEDs) to outputs
	
	LATB	= 0b00000000;
	TRISB	= 0b11111111;		// RB7..0 (DATA buttons) to inputs
	RBPU	= 0;
	WPUB	= 0b11111111;		// with pull-ups

	LATC	= 0b01000000;
	TRISC	= 0b10100101;		// RC7 (RXD), RC5 (LOAD button), RC2 (SAVE button) and RC0 (RUN/STOP button) to inputs, RC6 (TXD), RC1 (RUN/STOP LED) and all unused to outputs
	
	LATD	= 0b00000000;
	TRISD	= 0b00000000;		// RD7..0 (ADDRESS LEDs) to outputs
	
	LATE	= 0b00000000;
	TRISE	= 0b00001111;		// RE3 (NEXT button), RE2 (PREV button), RE1 (SAVE button) and RE0 (GOTO button) to inputs

	// initialize Timer 0 for 16 MHz (Fosc) / 4 (Fcyc) / 64 (prescale) / 65536 = 954 mHz (1.049 S period)
	T0CON	= 0b10000101;
	
	// initialize Timer 1 for 16 MHz (Fosc) / 4 (Fcyc) / 1 (prescale) / 65536 = 61.035 Hz (16.384 mS period)
	T1CON	= 0b10000001;
	
	// initialize Timer 2 for 16 MHz (Fosc) / 4 (Fcyc) / 4 (prescale) / 100 (PR2 + 1) / 10 (postscale) = 1 KHz (1 mS period)
	PR2		= 100 - 1;
	T2CON	= 0b01001101;

	// initialize UART for 9600 baud
	SPBRG	= 16000000 / 9600 / 64 - 1;
	SPEN    = 1;				// enable serial port
	TXEN    = 1;				// enable transmitter
	CREN	= 1;				// enable receiver
	RCIE	= 1;				// enable receive interrupt
	
	GIE = PEIE = 1;

	lamp_test();
	
	// main loop
	for( ;; )
	{
		t1ms = 0;

		// if timer rolled over, set millisecond event flag for one (and only one) loop iteration
		if( TMR2IF )
		{
			TMR2IF = 0;
			t1ms = 1;
		}
		
		ui_process();
		process_fn();
	}
}

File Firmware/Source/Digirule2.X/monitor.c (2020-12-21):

#include "digirule2.h"
#include <ctype.h>

#pragma warning disable 1481	// disable nuisance warning

#define BEL		'\x07'
#define CR		'\x0D'
#define ESC		'\x1B'

#define DISASM_LINES	12

static void state_prompt( void );
static void state_prompt2( void );
static void state_prompt3( void );

static void state_display_memory( void );
static void state_display_memory2( void );
static void state_display_memory3( void );
static void state_display_memory4( void );
static void state_display_memory5( void );
static void state_display_memory6( void );
static void state_display_memory7( void );
static void state_display_memory8( void );
static void state_display_memory9( void );
static void state_display_memory10( void );
static void state_display_memory11( void );
static void state_display_memory12( void );
static void state_display_memory13( void );

static void state_disassemble_memory( void );
static void state_disassemble_memory2( void );
static void state_disassemble_memory3( void );
static void state_disassemble_memory4( void );
static void state_disassemble_memory5( void );
static void state_disassemble_memory6( void );
static void state_disassemble_memory7( void );
static void state_disassemble_memory8( void );
static void state_disassemble_memory9( void );
static void state_disassemble_memory10( void );
static void state_disassemble_memory11( void );
static void state_disassemble_memory12( void );
static void state_disassemble_memory13( void );

static void state_edit_memory( void );
static void state_edit_memory2( void );
static void state_edit_memory3( void );
static void state_edit_memory4( void );
static void state_edit_memory5( void );
static void state_edit_memory6( void );
static void state_edit_memory7( void );
static void state_edit_memory8( void );
static void state_edit_memory9( void );
static void state_edit_memory10( void );
static void state_edit_memory11( void );
static void state_edit_memory12( void );
static void state_edit_memory13( void );
static void state_edit_memory14( void );

static void state_fill_memory( void );
static void state_fill_memory2( void );
static void state_fill_memory3( void );
static void state_fill_memory4( void );
static void state_fill_memory5( void );
static void state_fill_memory6( void );
static void state_fill_memory7( void );
static void state_fill_memory8( void );
static void state_fill_memory9( void );
static void state_fill_memory10( void );

static void state_load_memory( void );
static void state_load_memory2( void );

static void state_save_memory( void );
static void state_save_memory2( void );

static void state_display_registers( void );
static void state_display_registers2( void );
static void state_display_registers3( void );
static void state_display_registers4( void );
static void state_display_registers5( void );
static void state_display_registers6( void );
static void state_display_registers7( void );
static void state_display_registers8( void );
static void state_display_registers9( void );
static void state_display_registers10( void );
static void state_display_registers11( void );
static void state_display_registers12( void );
static void state_display_registers13( void );
static void state_display_registers14( void );
static void state_display_registers15( void );
static void state_display_registers16( void );
static void state_display_registers17( void );
static void state_display_registers18( void );
static void state_display_registers19( void );
static void state_display_registers20( void );
static void state_display_registers21( void );
static void state_display_registers22( void );
static void state_display_registers23( void );
static void state_display_registers24( void );
static void state_display_registers25( void );
static void state_display_registers26( void );
static void state_display_registers27( void );

static void state_edit_accumulator( void );
static void state_edit_accumulator2( void );
static void state_edit_accumulator3( void );
static void state_edit_accumulator4( void );
static void state_edit_accumulator5( void );
static void state_edit_accumulator6( void );
static void state_edit_accumulator7( void );

static void state_edit_breakpoint( void );
static void state_edit_breakpoint2( void );
static void state_edit_breakpoint3( void );
static void state_edit_breakpoint4( void );
static void state_edit_breakpoint5( void );
static void state_edit_breakpoint6( void );
static void state_edit_breakpoint7( void );

static void state_edit_program_counter( void );
static void state_edit_program_counter2( void );
static void state_edit_program_counter3( void );
static void state_edit_program_counter4( void );
static void state_edit_program_counter5( void );
static void state_edit_program_counter6( void );
static void state_edit_program_counter7( void );

static void state_run( void );
static void state_run2( void );

static void state_quit( void );
static void state_done( void );

///////////////////////////////////////////////////////////////////////////////
// public data

bool_t monitor_active;

///////////////////////////////////////////////////////////////////////////////
// private data

static const char
	menu[] =										"\r\n"
		"Digirule 2U Debug Monitor | " BUILD_DATE	"\r\n"
													"\r\n"
		"  D - Display Memory"						"\r\n"
		"  I - Disassemble Memory"					"\r\n"
		"  E - Edit Memory"							"\r\n"
		"  F - Fill Memory"							"\r\n"
		"  L - Load Memory"							"\r\n"
		"  V - Save Memory"							"\r\n"
													"\r\n"
		"  R - Display Registers"					"\r\n"
		"  A - Edit Accumulator"					"\r\n"
		"  B - Edit Breakpoint"						"\r\n"
		"  P - Edit Program Counter"				"\r\n"
													"\r\n"
		"  G - Go (Run)"							"\r\n"
		"  S - Step"								"\r\n"
		"  Z - Reset CPU"							"\r\n"
													"\r\n"
		"  ? - Display Menu"						"\r\n"
		"  Q - Quit"								"\r\n"
													"\r\n",
	*p;

static uint8 lines;
static union8_t address, end_address, data, breakpoint;
static void (*state)( void );
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

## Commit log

2020-12-21 Initial commit of files.
    [Digirule 2U BOM 21 December 2020.xlsx, PicknPlace.csv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]
2021-01-17 Add files via upload
    Prevent dirty buffer overflow on location counter out of range.
    [adr2.h]
